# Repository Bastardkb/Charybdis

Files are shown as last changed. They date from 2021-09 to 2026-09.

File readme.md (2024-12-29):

# Charybdis

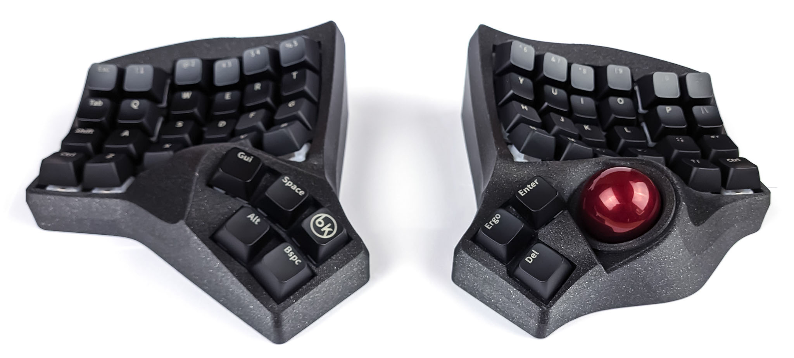
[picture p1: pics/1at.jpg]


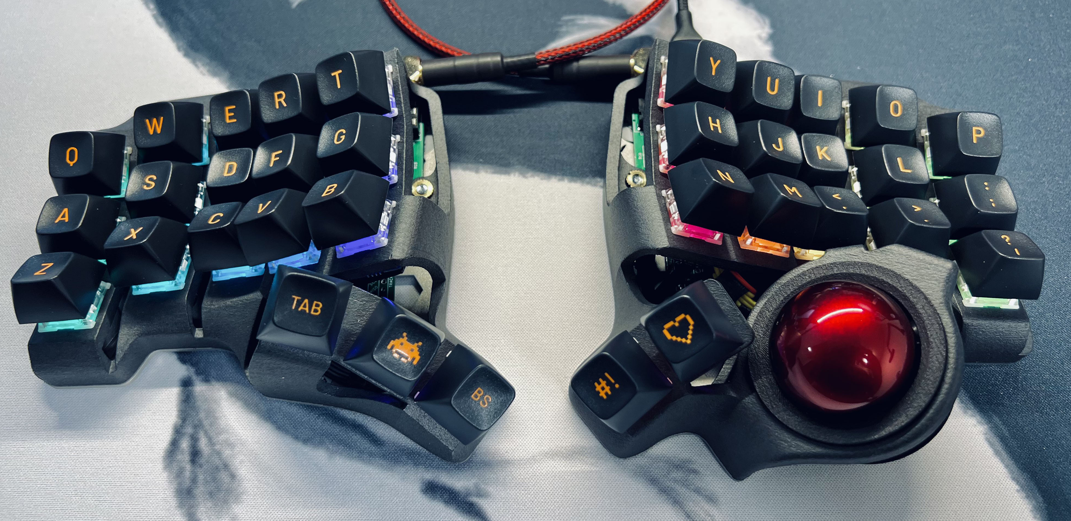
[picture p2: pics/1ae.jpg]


An ergonomic keyboard with integrated trackball.

Engineered to be a full mouse replacement solution with high-quality, custom-developed components.

There are 4x6, 3x6 "Mini" and 3x5 "Nano" versions.

Made to be used with the [Scylla](https://github.com/Bastardkb/Scylla), [TKB Mini](https://github.com/Bastardkb/TBK-Mini) or [Skeletyl](https://github.com/Bastardkb/Skeletyl) on the other half.

# Required components

## 3d prints - cases

The STL files are included in this Github repository, in the `files` folder.

You can find detailed instructions on how to print the case here:

https://docs.bastardkb.com/help/dactyl_print.html

Depending on which keyboard you are building, you will need different prints. There is a list in the table below - depending on the version number, the names will slightly vary. 

This repository is always updated with the latest version of the 3d models, and they are compatible with previous versions. For example, `charybdis.stl` might reference `charybdis3_v131.stl`. 

The 3d files might have the `stl` or `3mf` extension, depending on time of release. The extension type does not matter when slicing and printing.

**3d prints - 4x6**

There are two versions available for the Charybdis 4x6: `MK1`, and `MK2`. You can find the required files in their respective folder.

In the below table are listed the required files to construct the `MK2`, as that's the one most up to date.
The files that are compatible with both `MK1` and `MK2` are in the `4x6` folder.

| Description | File | Notes |
| --- | --- | --- |
| Right case | `4x6/MK2/charybdis.stl` | |
| Left case | | Download from the [Scylla repository](https://github.com/Bastardkb/Scylla) |
| Right plate | `4x6//MK2/plate_shield2.stl` | |
| Left plate | | Download from the [Scylla repository](https://github.com/Bastardkb/Scylla) |
| Adapter - top | `4x6/adapter_top.stl` | There is a different adapter for the 4x6 and 3x5, make sure to grab the one in the 4x6 folder ! |
| Adapter - bottom | `adapter_bottom.stl` | |
| Tent - right | `4x6/tent_alien.stl` | Optional 30 degree tent* |
| Tent - left | `4x6/tent_alien.stl` | Optional 30 degree tent, mirror the file for left* |

*The 30 degree tents are compatible with both Charybdis MK1 and MK2.

**3d prints - 3x6**

| Description | File | Notes |
| --- | --- | --- |
| Right case | `3x6 mini/Cmini.stl` | |
| Left case | | Download from the [TBK Mini repository](https://github.com/bastardkb/tbk-Mini), mirror the file for left |
| Right plate | `3x6 mini/plate.stl` | |
| Left plate | | Download from the [TBK Mini repository](https://github.com/bastardkb/tbk-Mini), mirror the file for left |
| Adapter - top | `3x5 nano/adapter_top.stl` | The 3x6 Mini uses the same top adapter as the 3x5 Nano |
| Adapter - bottom | `adapter_bottom.stl` | |
| Tent - right | `3x6 mini/tent.stl` | Optional tent* |
| Tent - left | `3x6 mini/tent.stl` | Optional tent, mirror the file for left* |

*If you are printing tents for the Charybdis Mini, there are both 30 and 5 degree versions available.

**3d prints - 3x5**

| Description | File | Notes |
| --- | --- | --- |
| Right case | `3x5 nano/charybdisnano.stl` | |
| Left case | | Download from the [Skeletyl repository](https://github.com/bastardkb/skeletyl), mirror the file for left |
| Right plate | `3x5 nano/plate.stl` | |
| Left plate | | Download from the [Skeletyl repository](https://github.com/bastardkb/skeletyl), mirror the file for left |
| Adapter - top | `3x5 nano/adapter_top.stl` | There is a different adapter for the 4x6 and 3x5, make sure to grab the one in the 3x5 folder ! |
| Adapter - bottom | `adapter_bottom.stl` | |
| Tent - right | `3x5 nano/tent/alien/tent.stl` | Optional tent* |
| Tent - left | `3x5 nano/tent/alien/tent.stl` | Optional tent, mirror the file for left* |

*If you are printing tents, there are multiple ones available for the Charybdis Nano. We recommend using the latest design which is the strongest and easiest to print - the alien version. There are both 30 and 15 degree versions available.

## Get a kit from BastardKB

You can get a full Kit, including case and all PCBs and electronics required on the shop:
https://bastardkb.com/

If you want to print the case yourself, you can also get just the electronics Kit.

## Electronic components

If you are sourcing the electronic components yourself, you can find a BOM in the [BOM](electronics_bom.md) file.

## Mods

There are some mods to add BTUs or ball bearings, check the [mods folder](files/mods/).

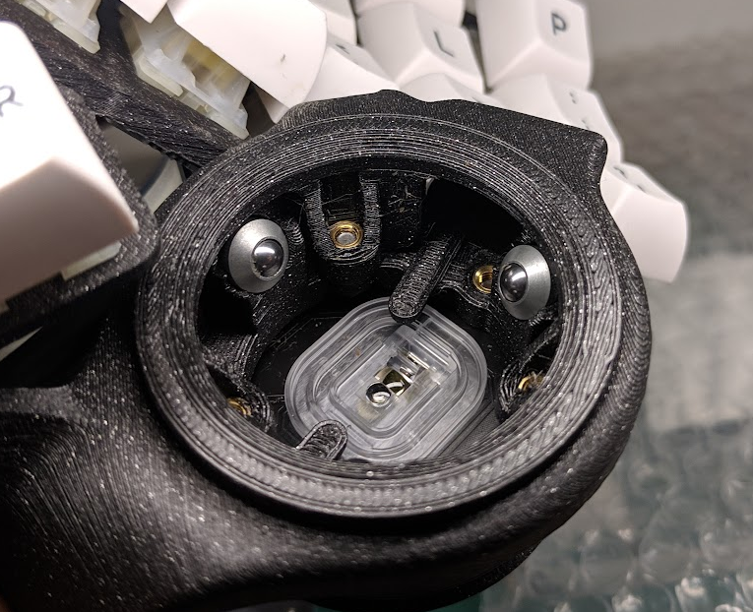
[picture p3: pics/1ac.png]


# Build guide

You can find detailed instruction on the online documentation linked below.

# Links

- Discord: https://bastardkb.com/discord
- Website: https://bastardkb.com/
- Docs: https://docs.bastardkb.com

# License 

This work is licensed under a Creative Commons Attribution-NonCommercial-ShareAlike 4.0 International License.

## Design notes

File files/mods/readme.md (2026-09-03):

# Table of contents

- [Table of contents](#table-of-contents)
- [Charybdis - generic](#charybdis---generic)
  - [BTU Mod](#btu-mod)
  - [Veichu Bearing Mod](#veichu-bearing-mod)
  - [Static Bearing Mod - Veichu drop-in replacement](#static-bearing-mod---veichu-drop-in-replacement)
  - [Static Bearing Mod](#static-bearing-mod)
  - [Static Bearing Mod - with screws](#static-bearing-mod---with-screws)
    - [Upgraded inserts for the Static Bearing Mod](#upgraded-inserts-for-the-static-bearing-mod)
  - [Trackpad mod for the Charybdis](#trackpad-mod-for-the-charybdis)
  - [Alternative sensors](#alternative-sensors)
  - [Snapfit PCB Case](#snapfit-pcb-case)
  - [AA Battery Holder](#aa-battery-holder)
  - [Trackball retainers](#trackball-retainers)
    - [PMW3360 PCB](#pmw3360-pcb)
    - [4x6 / PMW3610](#4x6--pmw3610)
- [Charybdis](#charybdis)
  - [Palm Rest](#palm-rest)
    - [Straight mod](#straight-mod)
    - [Slope mod](#slope-mod)
  - [Palm Rest for Charybdis 4x6 MKII](#palm-rest-for-charybdis-4x6-mkii)
  - [Modular adjustable tenting stand for Charybdis/Scylla](#modular-adjustable-tenting-stand-for-charybdisscylla)
    - [Base](#base)
    - [Variant with wrist wrest](#variant-with-wrist-wrest)
  - [Tripod mount plate](#tripod-mount-plate)
- [Charybdis Nano](#charybdis-nano)
  - [Midglow PCB for the Charybdis Nano tents](#midglow-pcb-for-the-charybdis-nano-tents)
  - [12mm Bosch BTU](#12mm-bosch-btu)
  - [Trackpad mod for the Charybdis Nano organic tents](#trackpad-mod-for-the-charybdis-nano-organic-tents)
  - [Chair Mount Plate](#chair-mount-plate)
  - [Modular Thumb Cluster](#modular-thumb-cluster)
  - [Sensor cover](#sensor-cover)

# Charybdis - generic

## BTU Mod

Very smooth, *very expensive*.



If you want to use BTUs rather than bearings, you will need to print the bottom adapter btu model, and source some 4.8mm BTUs.

The adapter model is designed around those: https://nl.rs-online.com/web/p/ball-transfer-units/7431408/.

Print the file in the `btu` folder.

## Veichu Bearing Mod

The veichu bearings are a cheaper alternative to the BTUs.

This uses the 7.5mm Veichu VCN310 variant.

They need to be press-fitted into the 3d print, as they have no screws.

There are 2 different versions in the `veichu` folder:

- [Bottom Veichu Model](veichu/veichu.stl) : uses M3 screw inserts
- [Bottom M3 Veichu Model](veichu/veichu_M3_screw.stl) : has M3 threads directly into the plastic, no inserts needed

## Static Bearing Mod - Veichu drop-in replacement

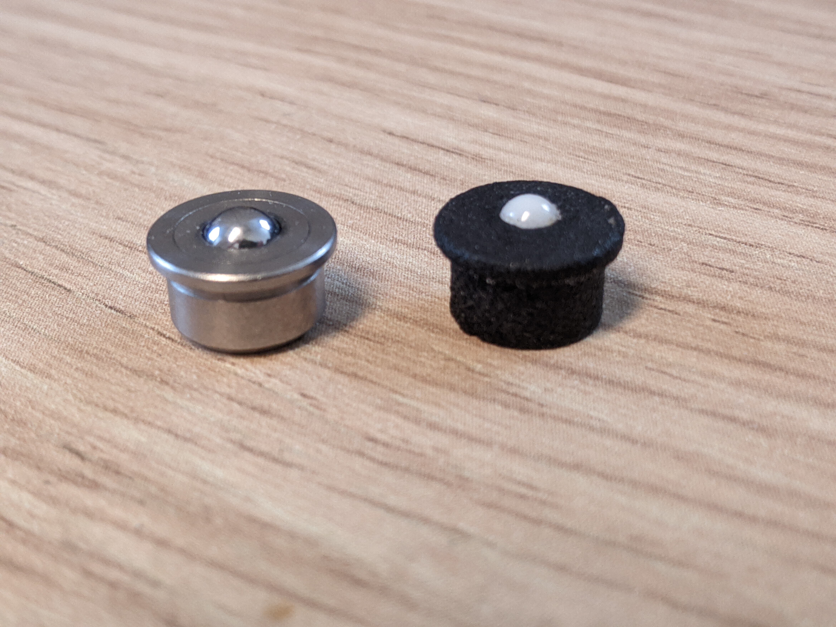
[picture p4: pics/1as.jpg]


A static bearing mod, that is a drop-in replacement for the 7.5mm Veichu VCN310 BTU.

The inserts were tested to work with MJF printing from JLCPCB. Different printing techniques have different tolerances, so you results may vary when printing with different techniques.

It was designed for 3mm ceramic balls. They press fit into the holders, can take quite a bit of force to press in. Recommend to press against a hard object like your desk.

Links:
- Use either version of the bottom models from the Veichu folder: [Bottom Veichu Model](veichu/veichu.stl) OR [Bottom M3 Veichu Model](veichu/veichu_M3_screw.stl)
- Use the [Inserts](Static-bearing-Veichu-drop-in/Static-bearing-holder_v221117.stl) from the static-bearing-veichu-drop-in folder.

## Static Bearing Mod

*This mod was made by a community member*.

Pretty smooth, *less expensive*.

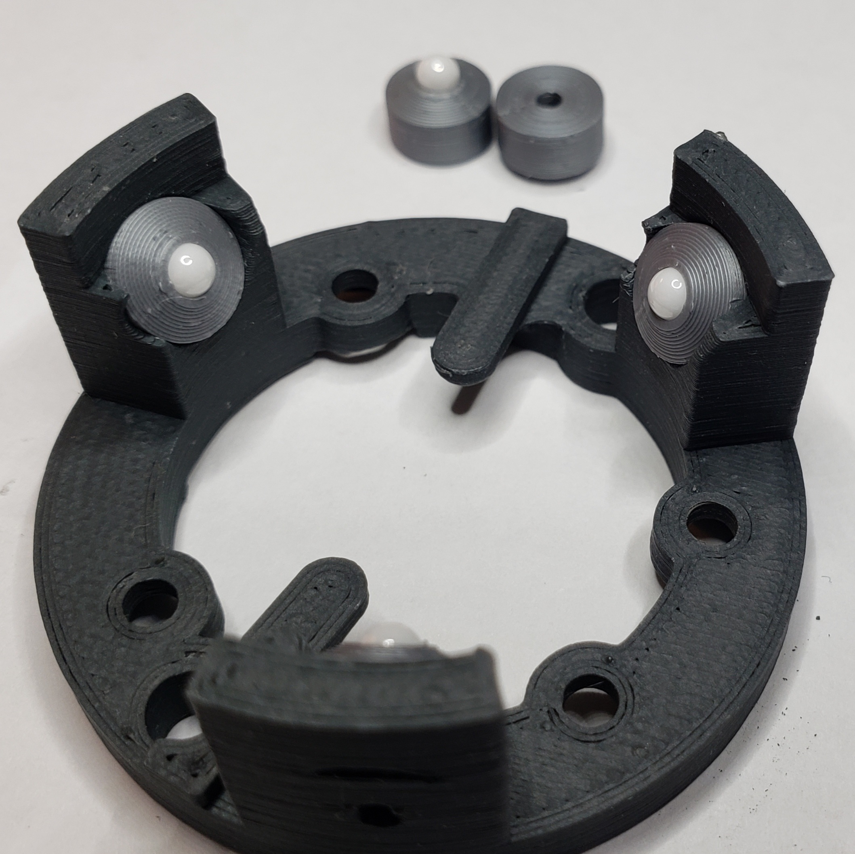
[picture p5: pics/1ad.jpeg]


You can use this option if you don't want to use bearings or buy the expensive BTU part.
There are files for 3.175mm (1/8"), and 2.5mm balls, you will need to print 3 of them as well as the bottom btu model.

Press the balls into the model then insert them into the modified [bottom btu model](btu/adapter_btu_bottom_v32.stl).

Links:
- [Bottom BTU Model](btu/adapter_btu_bottom_v32.stl)
- [Inserts](static-bearing) (choose either 3.175mm or 2.5mm)

## Static Bearing Mod - with screws

*This mod was made by a community member*.

Uses screws instead of pression fit to hold the ball inserts in the model. You will need M3 4mm screws.

Two versions : with 3.175mm balls, and 4mm balls.

Print:
- [Bottom BTU Model](static-bearing-screws/bottom.stl)
- [3.175mm insert](static-bearing-screws/balls-3.1mm/inserts.stl)
- [4mm insert](static-bearing-screws/balls-4mm/inserts.stl)

### Upgraded inserts for the Static Bearing Mod

*This mod was made by a community member*.

A bit taller of inserts, at 5mm tall, and a little more pronounced recess for the bearing ball.

The snap of the bearing ball is a little less intense as a result and gives more surface angle for the ball to rest on, resulting in a more secure seat for the ball.

Print:
- [Bottom BTU Model](static-bearing-screws/bottom.stl)
- [tall-inserts.stl](static-bearing-screws/balls-3.1mm/tall-inserts.stl)

Print and snap off supports. Sand the burrs if necessary.

## Trackpad mod for the Charybdis

Print the 2 files in the `mods/trackpad/trackball-holder` folder. Install in place of the trackball holder.
Connect the trackpad to sda, scl, vcc, gnd.

Required hardware:

| Part name | Amount | Link |
| --- | --- | --- |
| M4 8mm Torx Screw | 1 | Conrad |
| M4 screw insert, M4 X D6.0 X L5.0 | 1 | https://fr.aliexpress.com/item/4000232925592.html?spm=a2g0s.12269583.0.0.6aef4f282LZO4v |

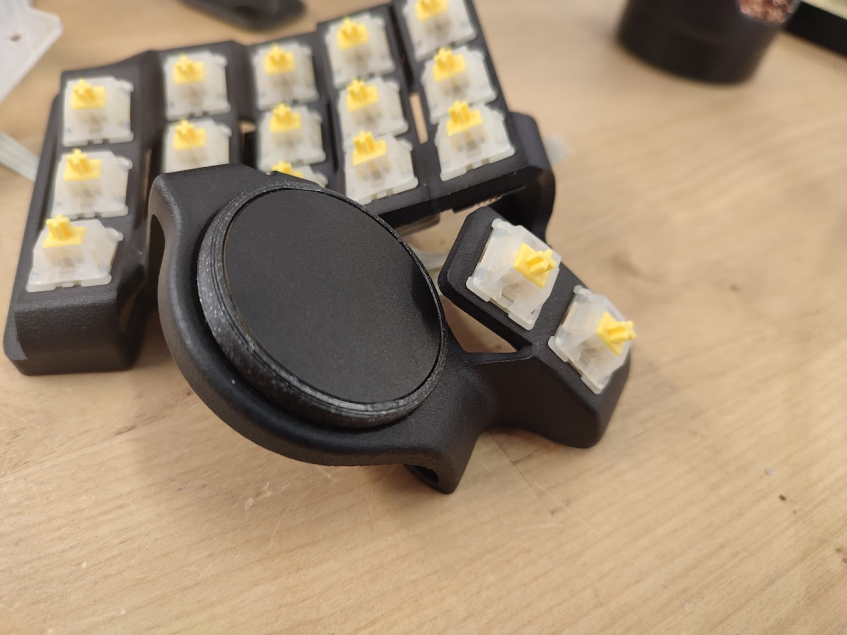
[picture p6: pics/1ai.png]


## Alternative sensors

*This mod was made by a community member*.

There are files in the [`bottom_adapter_alternative_sensors`](./bottom_adapter_alternative_sensors/README.md) directory to accomodate PMW3389 and ADNS9800 sensor PCBs.

## Snapfit PCB Case

*This mod was made by a community member*.

Made for the Charybdis Mini and Nano.

Details: [Snapfit PCB Case](./snapfit_pcb_case/).

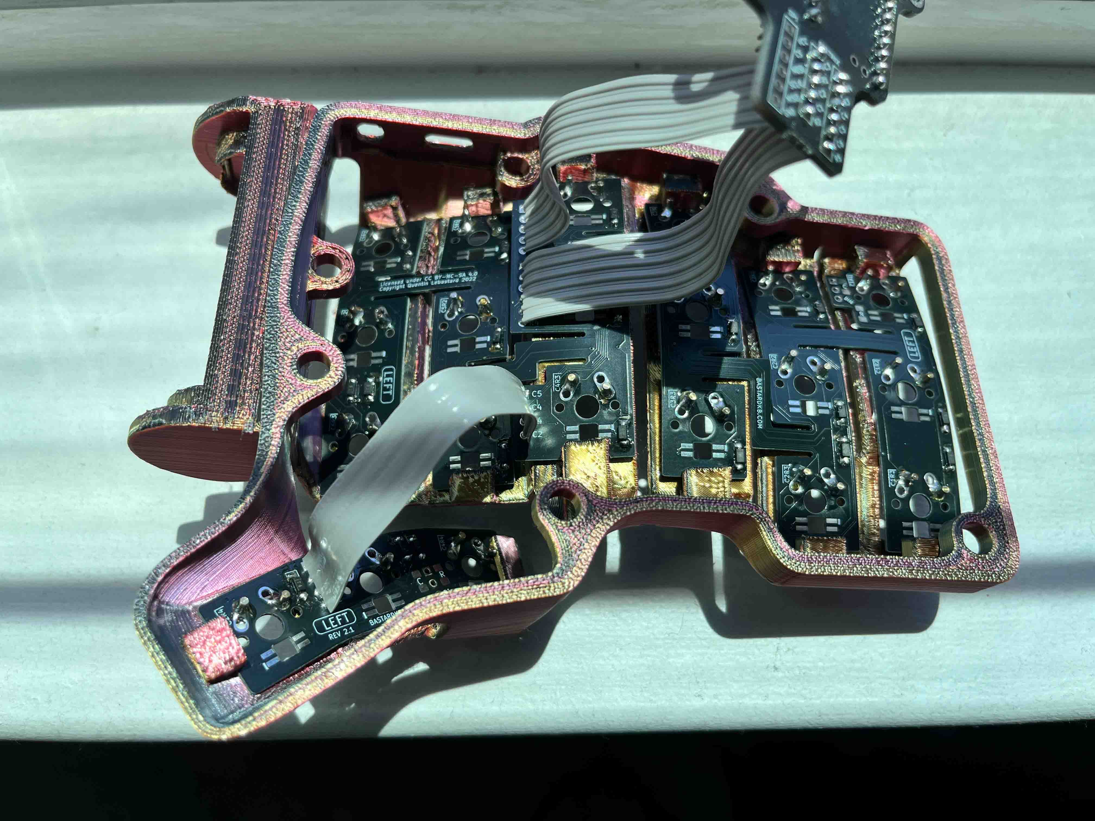
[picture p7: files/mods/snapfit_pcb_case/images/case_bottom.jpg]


## AA Battery Holder

*This mod was made by a community member*.

Made for the Charybdis Mini and Nano.

Details: [AA Battery Holder](./aa_3.7v_battery_holder/).

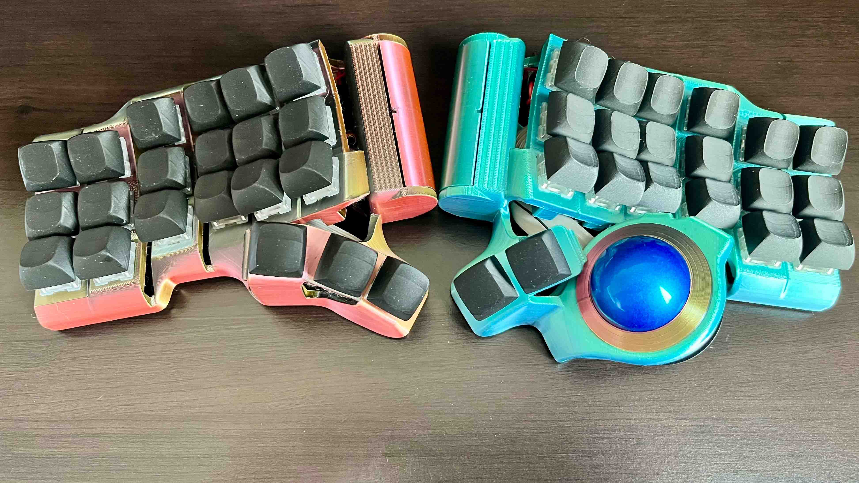
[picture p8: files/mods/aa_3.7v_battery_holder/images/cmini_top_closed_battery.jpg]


## Trackball retainers

*This mod was made by a community member*.

Use in place of the regular top adapter to prevent balls from falling.

### PMW3360 PCB

*This mod was made by a community member*.

The height of the model is adjusted for [static-beraing-screws](static-bearing-screws).

Rotating the ball may be difficult at first, but you will get used to it by putting it on and taking it off a few times and rotating it.
The screw holes of this part have an inner diameter (5mm) that allows you to glue M3 (x5x5) threaded inserts.

There are both 3x5 and 4x6 versions.

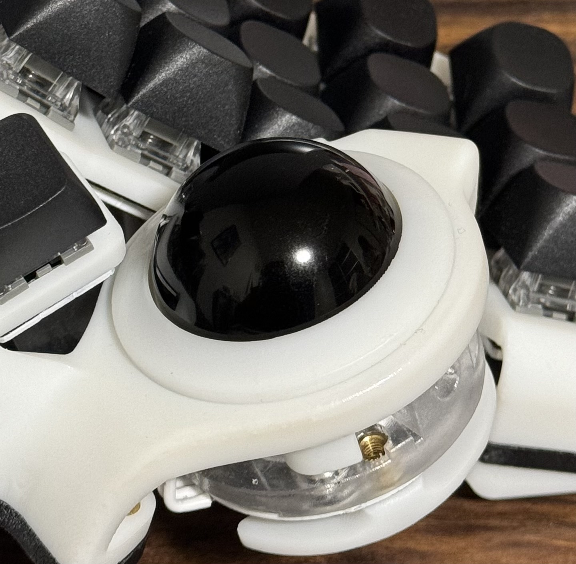
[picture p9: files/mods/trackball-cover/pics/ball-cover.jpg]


### 4x6 / PMW3610

*This mod was made by a community member*.

Specific model made for the PMW3610 PCB (for eg. bluetooth builds). Made for Zirconia 0.3mm ceramic balls.



Credit: Vzhao-L on Github.

# Charybdis

## Palm Rest

*This mod was made by a community member*.

Those palm rests are to be placed at the bottom of the keyboard, to support your palms. There are both sloped and straight versions.

For each version, there are 3 files:

- `STL`: for 3D printing
- `DWG`: for laser cutting
- `SLDPRT`: solidworks source file

The files for the Charybdis and Scylla are different:
- For the Charybdis, use the files in [4x6-palm-rest](4x6-palm-rest)
- For the Scylla, use the files from the [palm rest folder](https://github.com/Bastardkb/Scylla/tree/main/files/palm-rest)

### Straight mod
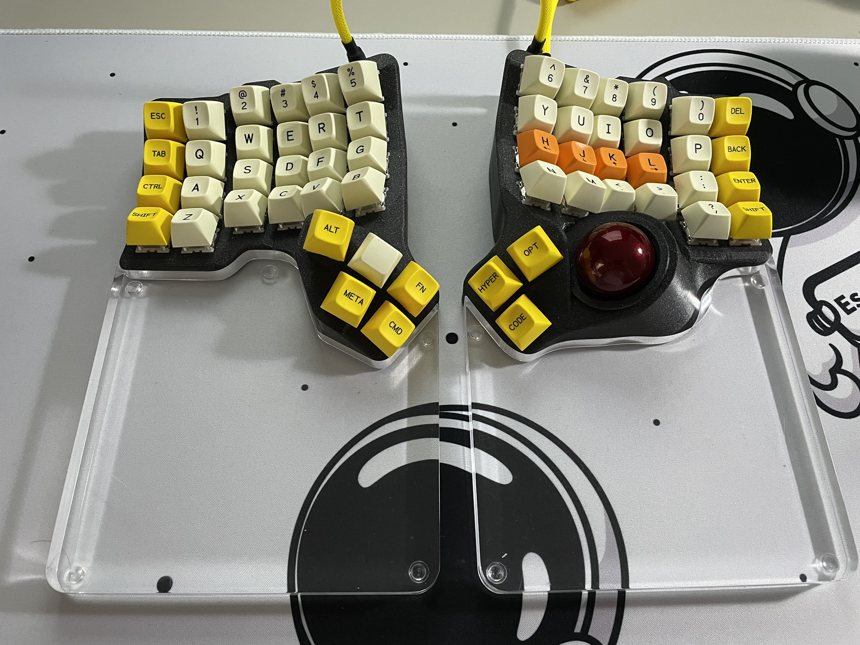
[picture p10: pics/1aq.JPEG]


### Slope mod
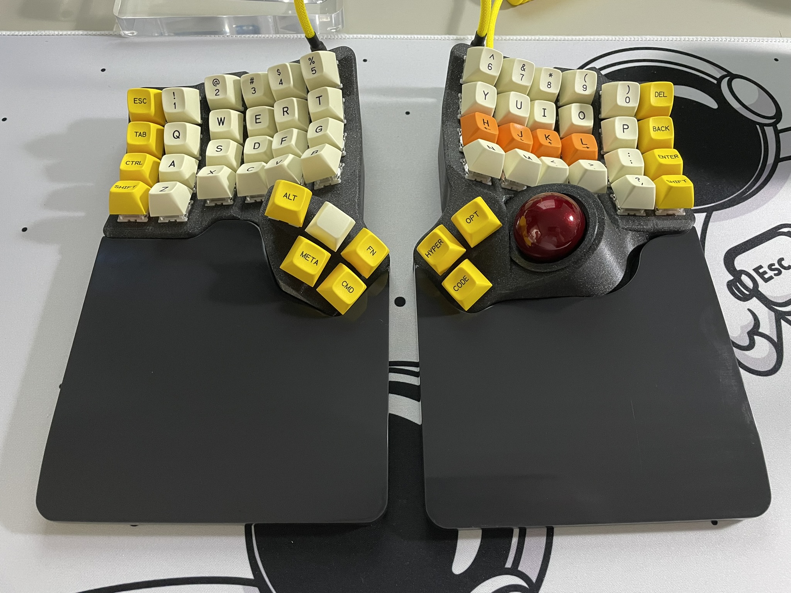
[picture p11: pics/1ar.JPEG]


## Palm Rest for Charybdis 4x6 MKII

*This mod was made by a community member*.

Wrist rests designed for larger cloth rubber mats like this one here: <https://aliexpress.com/item/1005004557222656.html>

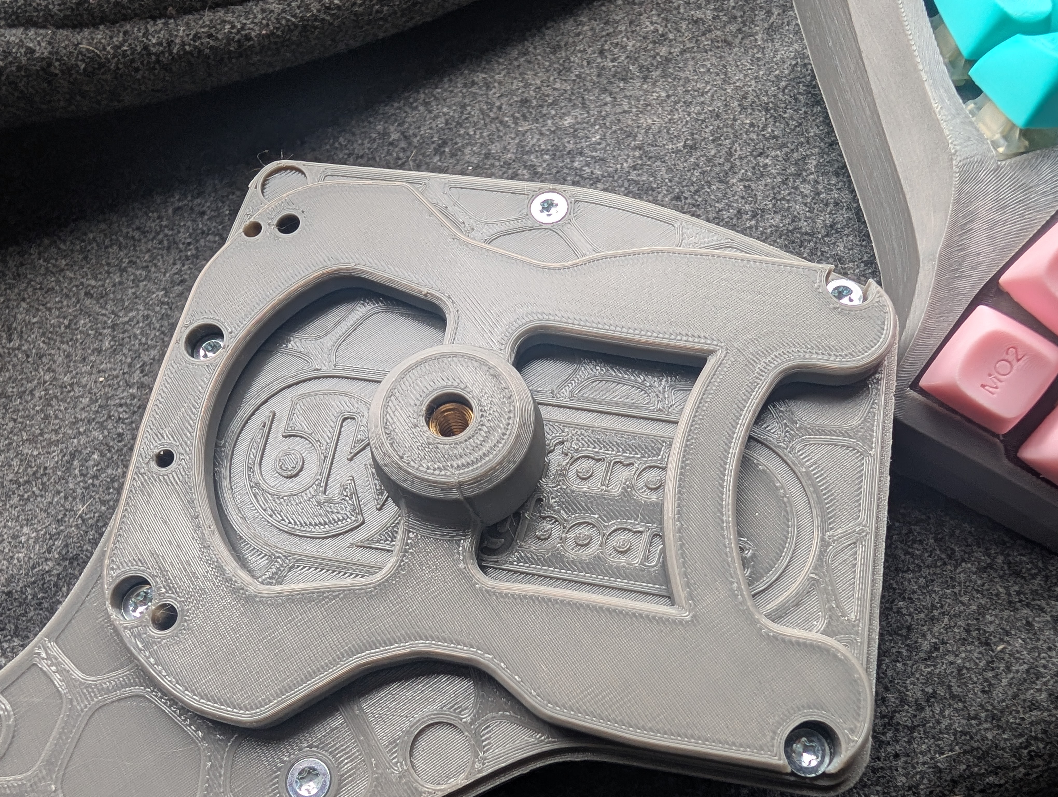
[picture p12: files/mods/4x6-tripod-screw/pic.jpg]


## Modular adjustable tenting stand for Charybdis/Scylla

*This mod was made by a community member*.

Details: [tenting-stand-with-wrist-pads/readme.md](tenting-stand-with-wrist-pads/readme.md)

### Base

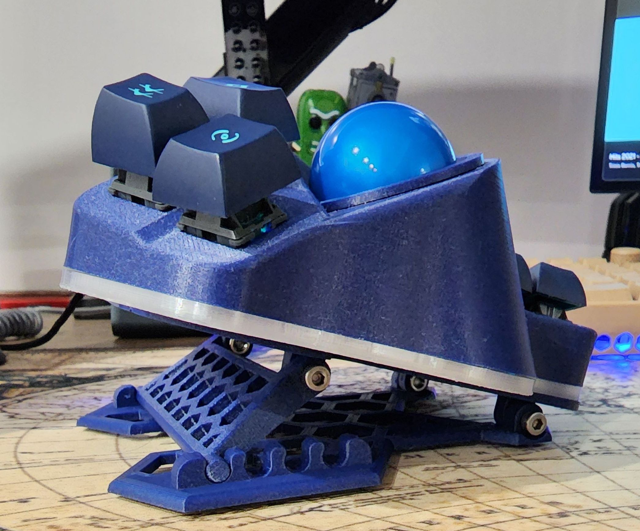
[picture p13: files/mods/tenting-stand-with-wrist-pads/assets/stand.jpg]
tenting stand


### Variant with wrist wrest

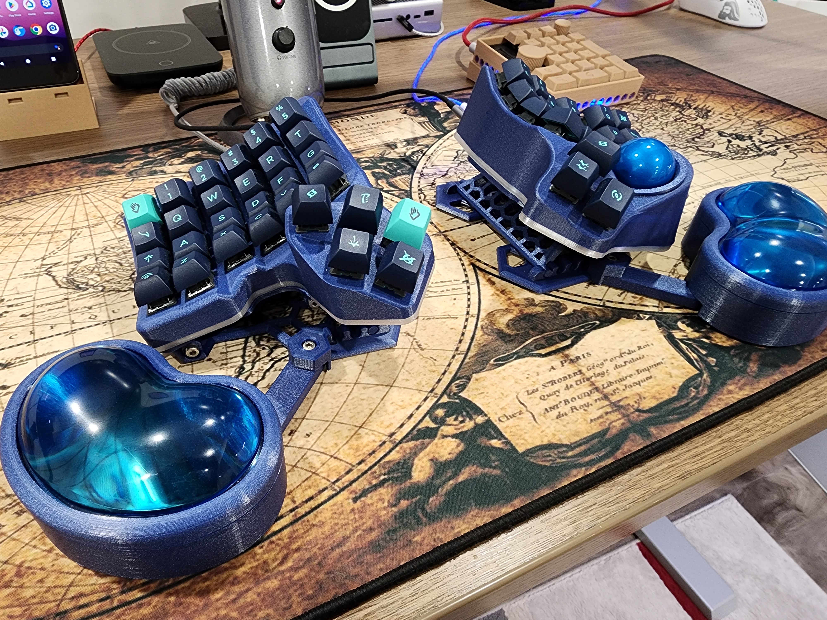
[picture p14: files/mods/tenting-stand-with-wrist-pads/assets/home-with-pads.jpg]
tending stand with wrist wrests


## Tripod mount plate

*This mod was made by a community member*.



This hefty plate mounts directly under the Charybdis plate and has an insert for a heated screw insert.
You can then screw it directly onto a tripod or magic arms. Screws into a standard 1/4 inch screw.

File is in `mods/4x6-tripod-screw`.

# Charybdis Nano

## Midglow PCB for the Charybdis Nano tents

Check repo here: https://github.com/Bastardkb/Charybdis-nano-tent-glow

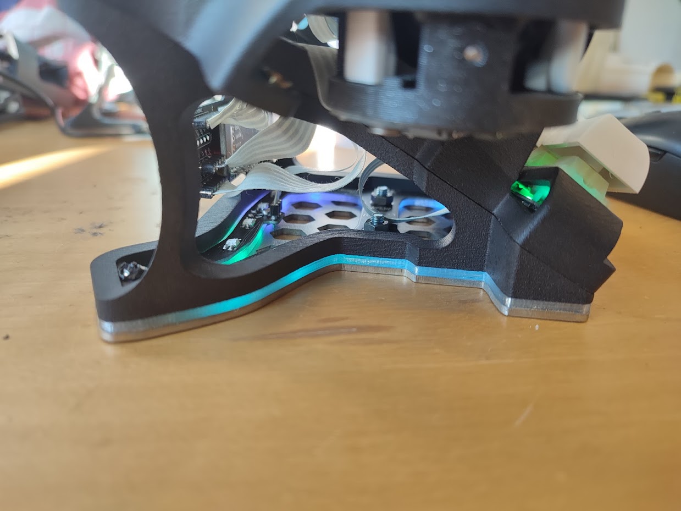
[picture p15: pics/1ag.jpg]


**Please note only the organic tent is compatible with the midglow rgb !**

## 12mm Bosch BTU

*This mod was made by a community member*.

This is an adapter for the BALL TRANSFER UNIT KU-B8-OFK R053010810 from Bosch Rexroth.

The barrel of this model is 12.6mm in diameter, with a 17mm flange which presented some challenges in creating enough space and keeping the trackball the proper distance from the sensor.

See files in `mods/12_6mm-btu-bottom-bracket`.



## Trackpad mod for the Charybdis Nano organic tents

Print the 2 files in the `mods/trackpad/3x5-tent` folder. Install on the organic tent, connect to sda, scl, vcc, gnd.

Required hardware:

| Part name | Amount | Link |
| --- | --- | --- |
| M4 8mm Torx Screw | 5 | Conrad |
| M4 screw insert, M4 X D6.0 X L5.0 | 5 | https://fr.aliexpress.com/item/4000232925592.html?spm=a2g0s.12269583.0.0.6aef4f282LZO4v |

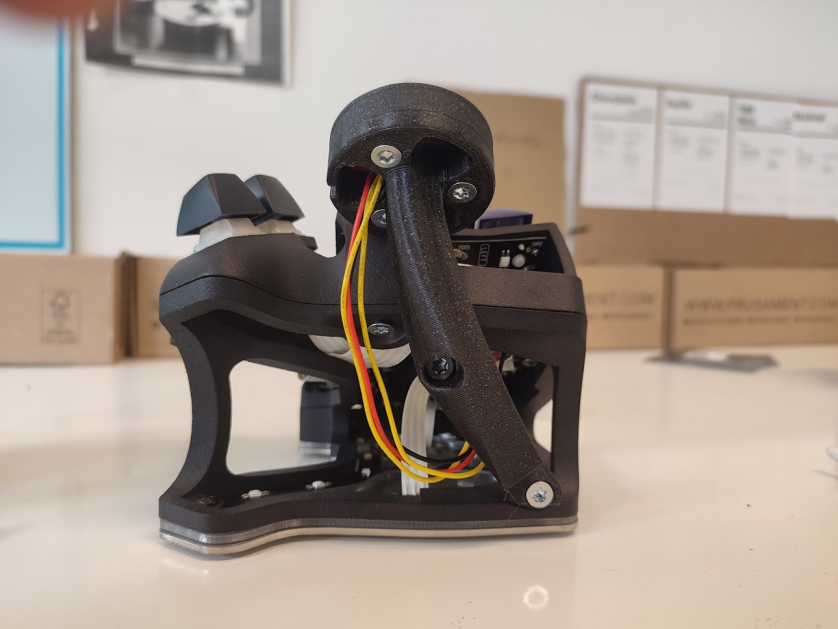
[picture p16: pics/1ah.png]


## Chair Mount Plate

*This mod was made by a community member*.

Alternate bottom plate for mounting to a chair or desk using standard camera mounting equipment. Fits 1/4 inch mounting bolt (1/4-20 UNC).
Found in the `3x5 nano/chairMountPlate` folder.

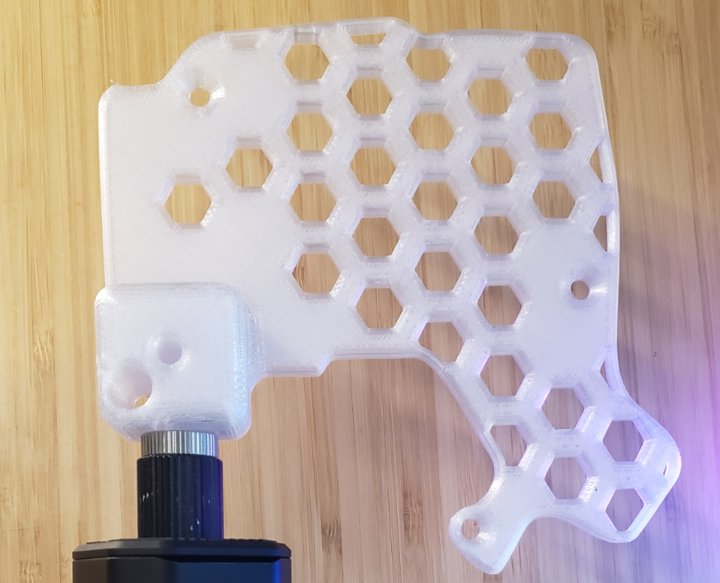
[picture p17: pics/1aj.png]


## Modular Thumb Cluster

*This mod was made by a community member*.

Based on the 3x5 Skeletyl/Charybdis Nano. This has a slightly modified plate, a 3 switch thumb cluster (ala Skeletyl), a 2 switch thumb cluster with the mount for a trackball/trackpad (ala Charybdis Nano) and a modified main body

Note: Below picture uses a standard Skeletyl main body that was cut to make room for the modular thumb cluster but a purpose printed main body should give better results!

| Part name | Amount | Link |
| --- | --- | --- |
| M4 8mm Torx Screw | 2 | Conrad |
| M4 screw insert, M4 X D6.0 X L5.0 | 2 | https://fr.aliexpress.com/item/4000232925592.html?spm=a2g0s.12269583.0.0.6aef4f282LZO4v |

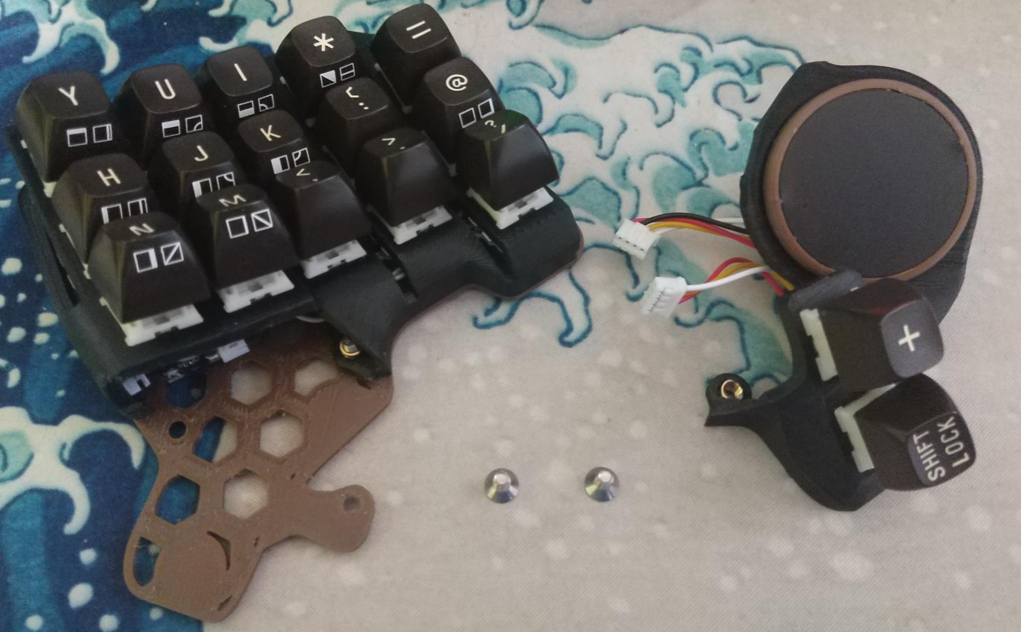
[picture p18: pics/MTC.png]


## Sensor cover

*This mod was made by a community member*.

A trackball sensor cover to be used in combination with the original bottom cover. Protects the sensor from outside elements.

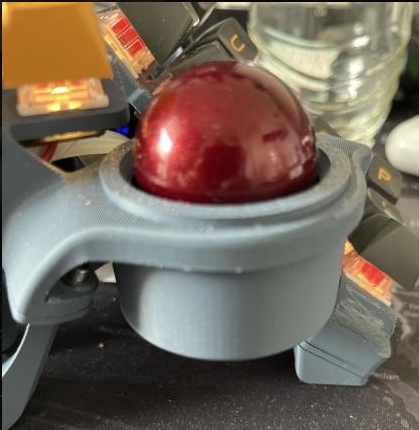
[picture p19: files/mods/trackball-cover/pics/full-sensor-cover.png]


File is in [trackball-cover](trackball-cover).

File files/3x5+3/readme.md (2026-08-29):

# 3x5+3
Modification of the Skeletyl to add a trackball, encoder and other mods. 
## Firmware
There is currently no official firmware for this build yet. Depending on which MCU is used the develop branch of QMK might need to be used.  

### Trackball
Base the firmware build off of bastardkb/charybdis/3x5 and copy the keymap from the Skeletyl to get the third thumb key on the right hand side.   
Trackball rotation adjustments would need to be made to the trackball orientation in the config.c file.  
### Encoder
To add the encoder The encoder functionality needs to be added as well as adding another key to the keymap for the push key on the encoder. The 12 LEDS need to be added to the map.   
Reference https://github.com/Bastardkb/Charybdis-EC11 for instructions on how it's wired.  
## Mounted Mods
This is a mod of the Skeletyl v4. This gives the ability to mount different mods to the inside or top of the keyboard.  
The mounting holes use M4 screws with heat inserts that are 45mm apart.  
JST XH 2.5mm connectors were used to attach the mods to the MCU board so they can be swapped out easily.

Assembled
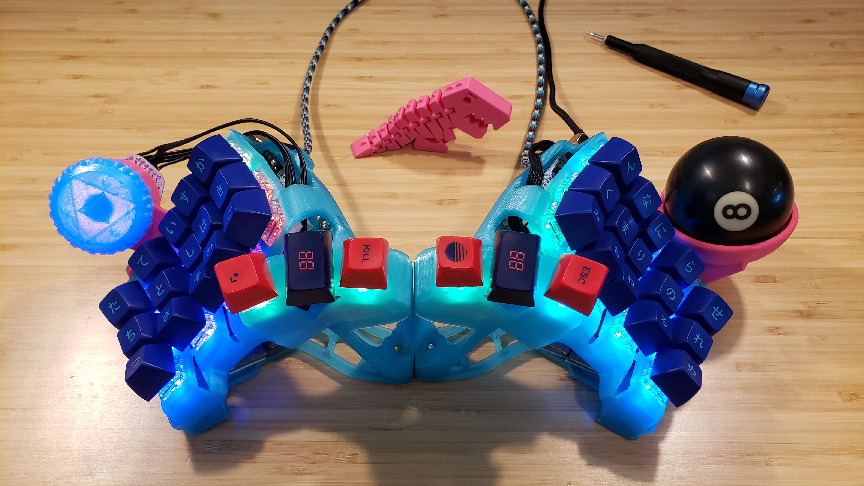
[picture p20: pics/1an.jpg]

Disassembled
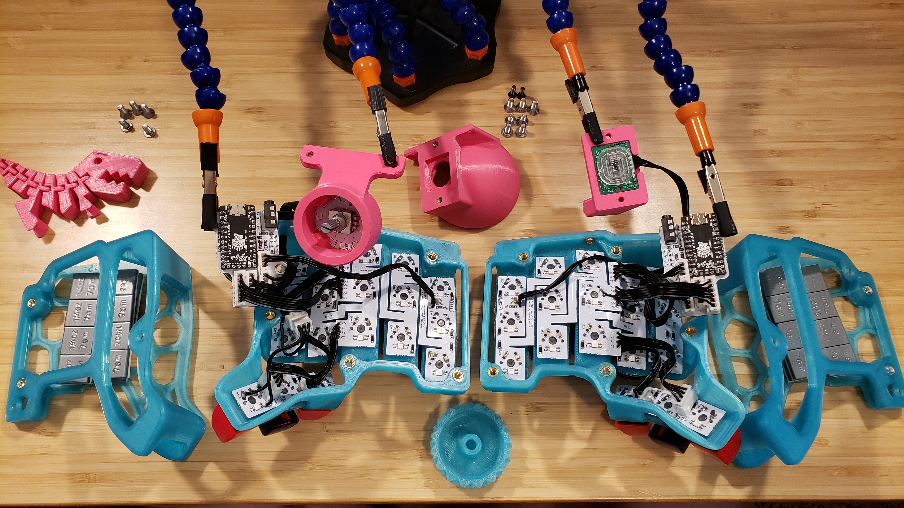
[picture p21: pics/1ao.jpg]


### Mods 
Currently only the top mount options has been developed.

#### Trackball Mod
##### Top Trackball
There are two of trackball sizes available 55mm or a 57.15 mm (2.25 inch) billiard ball.  
Two M3 screws are used to mount the cover/sensor board.
The ball bearings are 3.175mm (1/8 inch).  
They are designed for a pmw3360 or pmw3389 board from tindie.  
The charybdis-pmw-3360-sensor-pcb could be used but the bottom cover will not fit and the holes are slightly off but the heat insert could be adjusted to get it to work.  
There is a bottom version specific to the 30 degree tented version that has an angled stand to support the trackball weight.  
##### Inside Trackball
This mod uses a 34 mm trackball and the adapter from the Charybdis 3x5. This mod does work when not tented. When tented the trackball is not seated completely and does wobble.   
This could also be used to mount an encoder.  
Use the CharybdisRingMountMod file.  
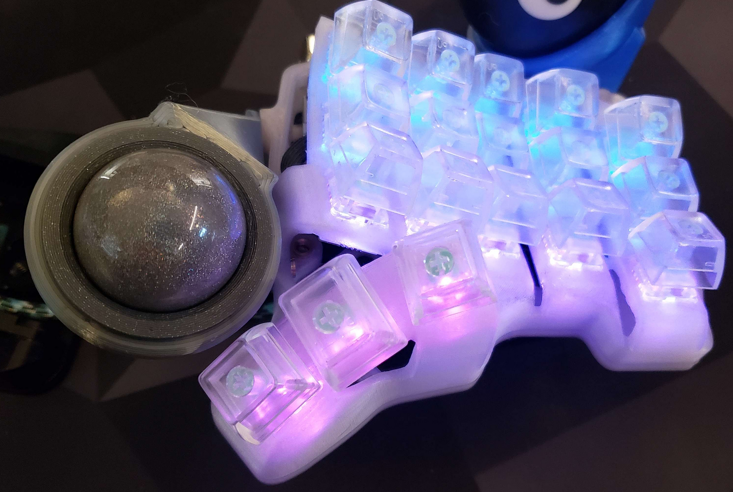
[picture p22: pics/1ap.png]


#### Encoder Mod
This uses the Charybdis EC11 pcb board with a 20mm tall EC11 encoder.  
The knobs provided use the round shaft.  
There are two knob variants a blank one and one with a second iteration Sierpiński triangle design. Both variants have domes for one finger top operation.  

### Plates
Any of the Skeletyl v4 plates can be used. The tenting models are in the Chaybdis/3x5 nano/tent the ones shown in the picture is the 30 degree alien tent with voronoi plate. Beware of interference with non tented options as the bottom of the mods protrude slightly.     
  
## HighTrackball and LowTrackball
This is a mod of the Skeletyl v3 to add the trackball mount to the inside of the keyboard.   
**A thick base plate or tenting is required for either version to sit flush on a surface.** 

*Note:* See [High Trackball File Variants](#high-trackball-file-variants) and [Low Trackball File Variants](#low-trackball-file-variants) for flat plates that work for the 3x5+3 High and Low Trackball builds. 

The tall version will not interfere with the base plate allowing any Skeletyl v3 base plates and tents to be used. 

The low version's trackball will interfere with the base plate requiring a cutout in the plate for it to fit. 

### Plates
The chair mount plates requires a heat insert for 1/4 inch camera mount threads.

High Version  
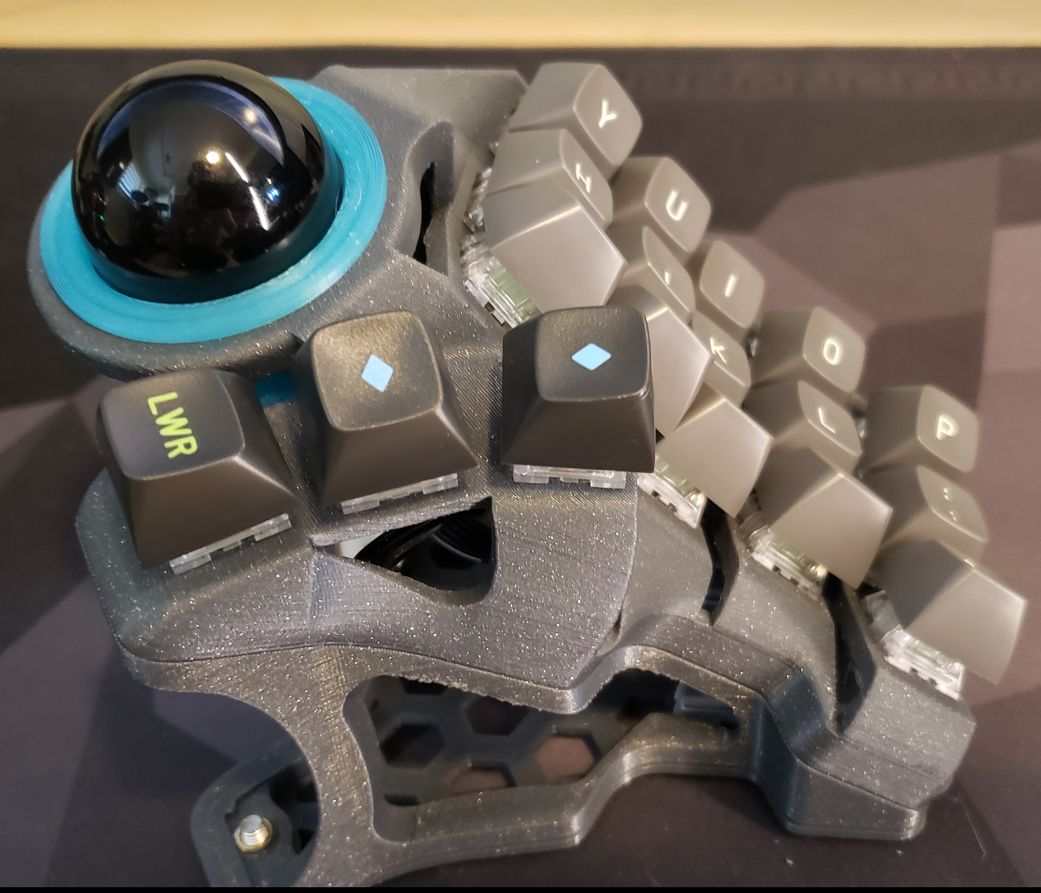
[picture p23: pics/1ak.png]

  
Low Version  
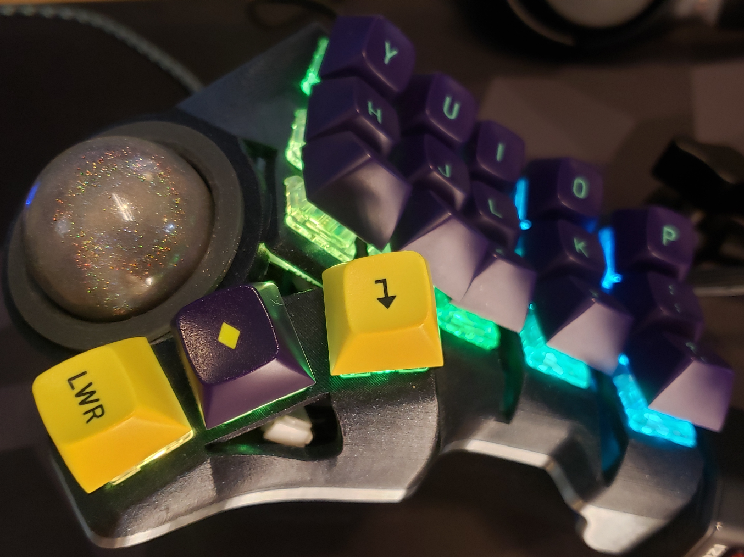
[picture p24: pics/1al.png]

  
The required cut in the plate to fit the trackball in the low version.  
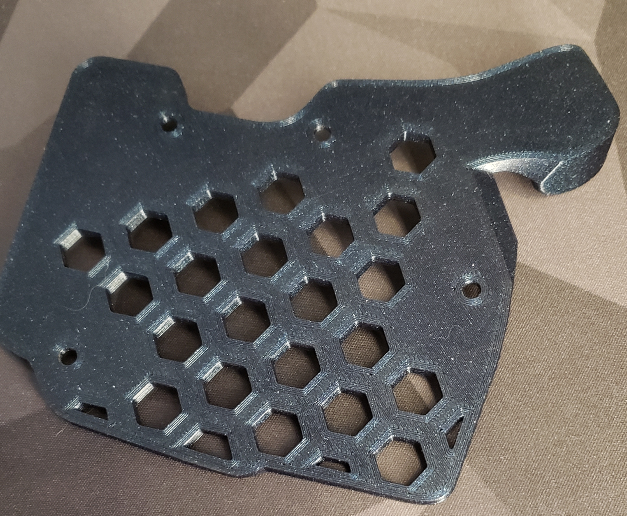
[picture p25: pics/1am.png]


### High Trackball File Variants

[flat_plate.stl](./HighTrackball/flat_plate.stl) lets you use the high trackball Charybdis flat on a desk, without a tent. It is the same as the low trackball [flat_plate.stl](./LowTrackball/flat_plate.stl), only without the cutout for the ball: the high trackball sits above the plate and never touches it. The two halves are mirrored, so print the plate once as is and once mirrored. [flat_plate.3mf](./HighTrackball/flat_plate.3mf) is the same plate in a format that is easier to open and edit.

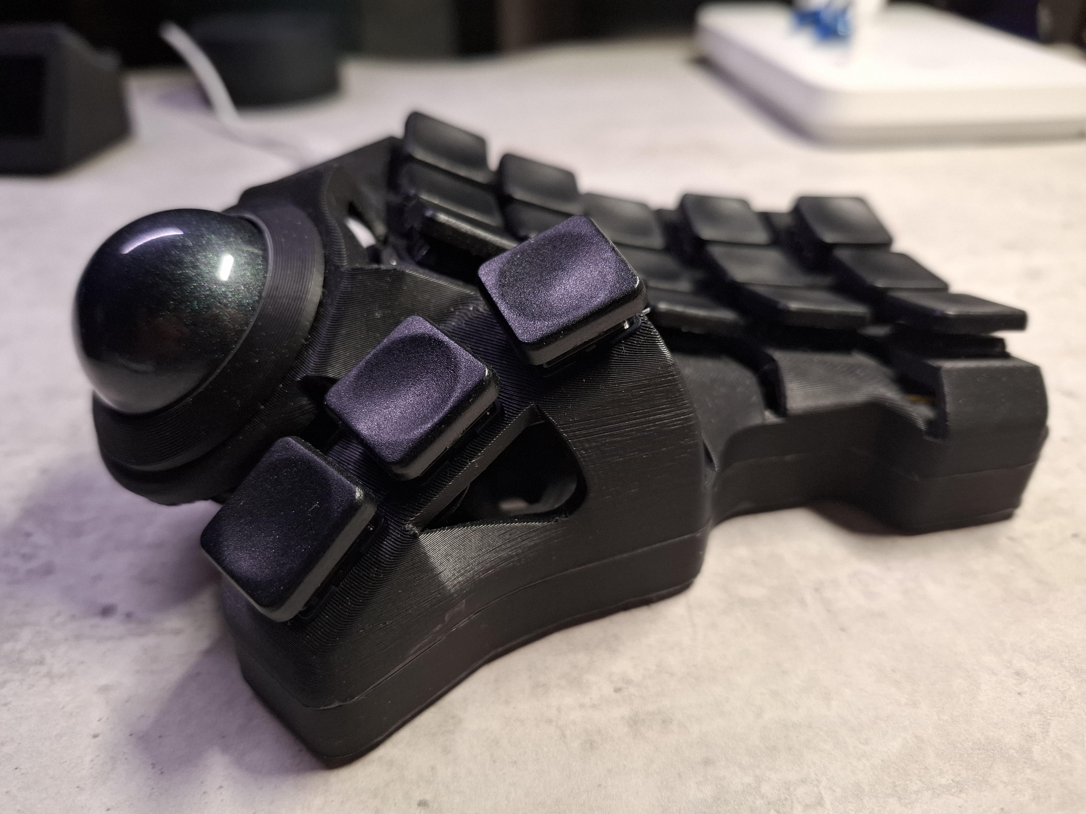
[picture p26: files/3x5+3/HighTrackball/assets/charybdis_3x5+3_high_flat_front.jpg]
charybdis_3x5+3_high_flat_front


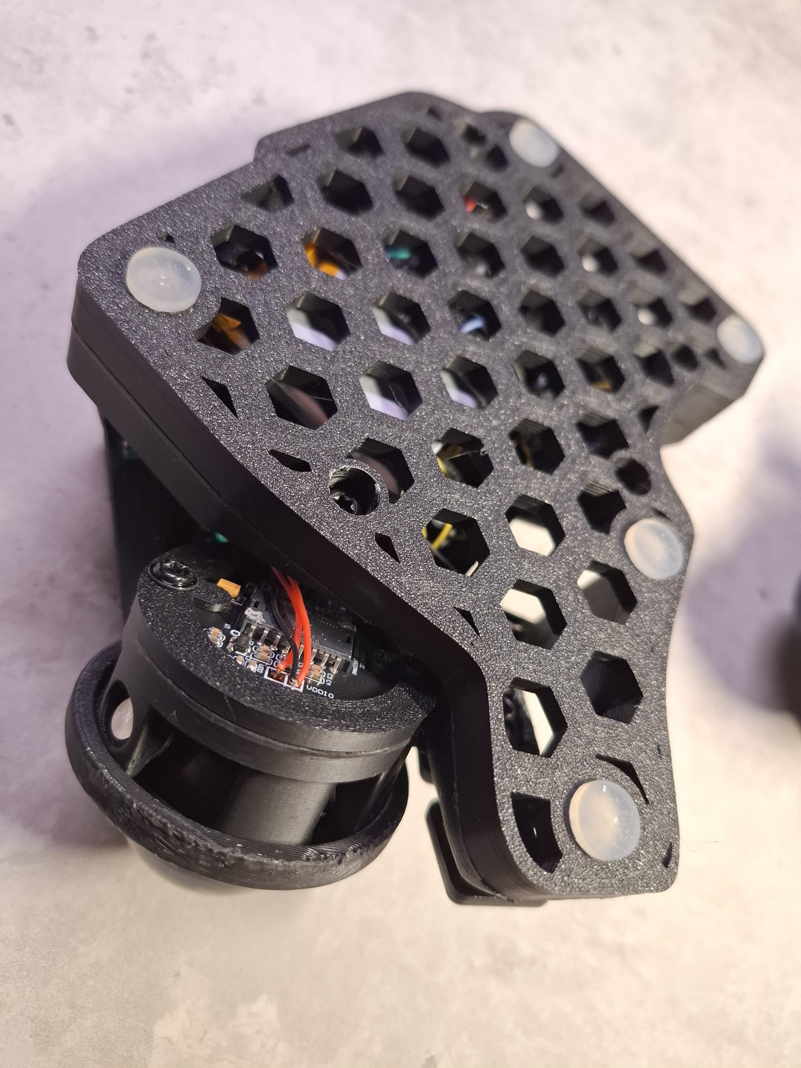
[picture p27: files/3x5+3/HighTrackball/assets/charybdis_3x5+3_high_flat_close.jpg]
charybdis_3x5+3_high_flat_close


### Low Trackball File Variants

If printing the low trackball Charybdis consider printing [3x5+3_low_clipped.stl](./LowTrackball/3x5+3_low_clipped.stl) as it removes the heat sink nut closest to the trackball mount so that it doesn't need to be clipped off aterwards. Additionally, [flat_plate.stl](./LowTrackball/flat_plate.stl) allows you to use the Charybdis without a tent.

charybdis_3x5+3_low_flat_front

charybdis_3x5+3_low_flat_close

Finally, if you are doing a handwire build then [mcu_holder.stl](./LowTrackball/mcu_holder.stl) will hold a KB2040 (or similar MCU), the TRRS jack, and a 6mm reset button.

mcu_holder_bottom

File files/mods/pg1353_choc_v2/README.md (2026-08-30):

# Kailh PG1353 (Choc V2) switches

The stock Charybdis cases are cut for MX switches. This mod is the 3x5+3 high trackball case re-cut for Kailh PG1353, sold as Choc V2.

Cutting Choc-sized windows is not enough on its own. A PG1350 (Choc V1) latches into printed plastic well enough, but the PG1353 latches are much smaller and get no grip at all, so the switches drop straight back out of the window.

The fix is two ordinary stapler staples melted into each switch window, one down each side. The latch then catches on the metal strip instead of on the plastic, and that holds: nothing has fallen out since. Taking a switch back out means bending its latches in first, otherwise they snap off.

The holes for the staples are already in the case model.

staple_in_window

A staple sitting in the switch window.

switch_retained

From below, with a switch fitted: the latches hook onto the staple.

switch_fit

How tightly the switches end up sitting in the case.

## Files

Modified from [3x5_3 high v2.stl](../../3x5%2B3/HighTrackball/3x5_3%20high%20v2.stl):

- [3x5_3_high_v2_pg1353_left.stl](./3x5_3_high_v2_pg1353_left.stl)
- [3x5_3_high_v2_pg1353_right.stl](./3x5_3_high_v2_pg1353_right.stl)

Each one also has a 3mf next to it, which is easier to open and edit.

The two halves are not mirror images of each other, so print both files as they are.

Read the section below before printing: this is one specific build, not a drop-in replacement for the stock case.

## How it differs from the stock case

**Choc-sized switch windows.** The stock case is cut for MX. Every window here is re-cut for Choc, with two extra holes per window for the staples.

**Hotswap sockets instead of a PCB.** The PG1353 body is shorter than the PG1350 and does not reach through the thickness of the case, so a PCB cannot meet the switch pins. Every switch has a Kailh hotswap socket soldered straight onto it and the matrix is hand wired. The socket sticks out to one side, and the case has small extra cut-outs for it. Those cut-outs are what stops the two halves from being mirror images.

**A trackball in both halves.** The left file is the mirrored trackball case, not a plain half. There is no version without a trackball; that one would have to be modelled.

**No jack opening.** This is a ZMK wireless build, so there is no hole for a TRRS jack.

matrix_wired

The matrix, rows and columns wired.

matrix_in_case

The wired matrix in the case, before the controller goes in.

## Staples

- No. 10 staples — the small ones for hand staplers, legs about 5 mm as they come.
- 72 of them: 36 switches, two per switch.
- Cut the legs down to 2–3 mm.

staple_length

- Push a leg into each hole and melt it in with a soldering iron, so the strip ends up flush along the side of the window.
- The staples sit in the gap between the switch body and the case wall. They come nowhere near the switch pins or the sockets.

assembled

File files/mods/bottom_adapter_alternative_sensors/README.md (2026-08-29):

# Bottom Adapter Alternative Sensors

- [Bottom Adapter Alternative Sensors](#bottom-adapter-alternative-sensors)
  - [ADNS-9800](#adns-9800)
  - [PMW-3389](#pmw-3389)
  - [PAW3360 / PMW3389 module](#paw3360--pmw3389-module)
    - [Orientation](#orientation)

## ADNS-9800

[adapter_v2_bottom_adns_9800](./adapter_v2_bottom_adns_9800.stl)

adns_9800_bottom
adns_9800_top

## PMW-3389

[adapter_v2_bottom_pmw_3389](./adapter_v2_bottom_pmw_3389.stl)

pmw_3389_bottom
pmw_3389_top

## PAW3360 / PMW3389 module

An adapter for the cheap sensor module sold on AliExpress as a "PAW3360/3389-Module", silkscreened `20240424`. Unlike the two above it is not a bottom adapter of its own — it is a thin plate that screws onto an existing ball holder in place of the original sensor PCB.

[adapter_paw3360_3389_module_20240424](./adapter_paw3360_3389_module_20240424.stl)

paw3360_3389_bottom
paw3360_3389_top

The sensor position is taken from the original Bastardkb sensor PCB, so the lens sits in the same place and at the same distance from the ball. It was printed and used on the [Veichu M3 holder](../veichu/veichu_M3_screw.stl). The other holders have not been tested, but they are all built around the original PCB, so it should fit those as well.

### Orientation

The module is symmetric and drops into the adapter either way round, but only one way is right: the row of solder pads must face the dot embossed on the adapter. The board sits off-centre in the adapter and the sensor sits off-centre on the board — the two offsets cancel out only in this orientation. Turned 180° they add up and the sensor no longer looks at the centre of the ball.

paw3360_3389_orientation

*The photo was taken with an earlier print that had a cut-out where the dot is now; the dot and the markings are drawn on.*

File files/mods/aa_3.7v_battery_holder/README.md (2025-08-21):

# Battery holder for wireless builds

The conventional wireless build for the Charybdis line of keyboards uses Li-Ion batteries, like the 401030 130mAh battery. 
The internal housing, which is specifically designed to be a wired keyboard, limits the battery size. 

Lower battery sizes offer less battery capacity, thereby reducing the battery life on the keyboard.

ZMK battery life can be computed here: https://zmk.dev/power-profiler

This mod provides (14500 3.7v Li-Ion battery) holders to the Charybdis. This will increase the battery capacity usable for Charybdis to 2500-3800mAh from current values of 130-300mAh. This repository contains files for the right and left cases for the "Mini" and "Nano" versions of the Charybdis.

## Compatibility
The following models have been confirmed working:

- Charybdis Mini with AA battery (14500 3.7v Li-Ion battery)
- Snap Fit Cases for Charybdis Mini

The following have not been tested:

- Charybdis Nano
- Tenting mechanisms

## 3D models

The files are in the `charybdis_nano` and `charybdis_mini` folder.

## Showcase

|   |
| :---------------------------------------: |
| Charybdis Mini With AA Battery (Top View) |

|                                                             |
| :-------------------------------------------------------------------------------------: |
| Charybdis Mini With AA Battery (Bottom View Showing Mill-Max Hotswap With Snap Fit PCB) |

|                                  |
| :--------------------------------------------------------------------: |
| Charybdis Mini With AA Battery (Top View Without Battery Holder Cover) |

## Build guide

A build guide can be found in the [build guide file](build_guide.md).

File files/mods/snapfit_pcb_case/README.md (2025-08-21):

# Snap Fit Cases for Charybdis Mini and Charybdis Nano

The conventional build for the Charybdis line of keyboards is to solder the switches to the PCB. This helps to hold the PCB firmly in place.

To make the Charybdis hot swappable, some force is required to keep the PCB pushed against the keyboard case. This can be achieved with:

- using copious amounts of hot glue and/or tape
- handwire each hotswap socket
- the snap fits in this repository

The snap fit files are tested for the Charybdis Mini. The rest of the keyboards have not been tested.

## 3D models

The files are in the `charybdis_nano` and `charybdis_mini` folder.

## Renders

Charybdis Mini:

|  |
| -------------------------------------- |
|                                        |

Charybdis Nano:

|  |
| ----------------------------------------------- |
|                                                 |

## Build images

This project is used to build the project "Charybdis Mini and Charybdis Nano with AA battery". Attached are images of the front and rear view of the Charybdis Mini case with snapfits and millmax-hotswappable PCBs.

Charybdis Mini bottom view:



Charybdis Mini top view:


## Installation

1. Insert the flexible PCBs by bending them and locking them in the snap fits
1. Exercise caution when bending the thumb PCB cluster as they might not be as flexible as the 3x6 or 3x5 PCB plates
1. In case you are unable to fit the PCBs in the snap fits: One potential check would be to ensure there are no supports under the snap fits

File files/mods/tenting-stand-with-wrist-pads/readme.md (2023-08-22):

# Modular adjustable tenting stand for Charybdis/Scylla

## Required hardware

| Part name | Amount | Amount with wrist supports | Link |
|---|---|---|---|
| M4 nuts | 8 | 12 | Anywhere |
| M4 bolts 14+mm length | 8  | 12 | Anywhere |
| For wrist support generic mouse gel pads from ali or amazon | 2 | 2 | [Ali](https://www.aliexpress.com/item/1005003137481242.html) or [Amzn](https://a.co/d/4aokloi) |

## Base

tenting stand

## Variant with wrist wrest

tending stand with wrist wrests

## Printing

### Base parts

- [Bottom - bottom.3mf](bottom.3mf)
- [Top plate - plate.3mf](plate.3mf) - This must be mirrored for another side
  
  Alternatively you can print remixed bottom case plates for Scylla/Charybdis, mirror appropriately if required. This should reduce several millimeters.
  
  - [Scylla bottom plate hinges](left-case-bottom-scylla.3mf)
  - [Charybdis bottom plate with hinges](right-case-bottom-charybdis.3mf)
  - [Charybdis 3x5+3 Low bottom plate with hinges](3x5+3_low_tent_plate.stl)

  Print them vertically like so: print-position
  
- [Tenting arm - tenting-arm.3mf](tenting-arm.3mf)

### Additional parts for wrist wrest

See folder `wrist-pad-variant-parts` for more files

- [Bottom plate with attachment](wrist-pad-variant-parts/bottom-with-pad-connector.3mf) - This must be mirrored for another side, also ensure pads arm attachment has supports.
- [Top part that hold gel pad - pads-holder.3mf](wrist-pad-variant-parts/pads-holder.3mf)
- [Bottom part that connects to the arm - pads-base.3mf](wrist-pad-variant-parts/pads-base.3mf)
  - [Bottom part that connects to the arm, but shorter by 5mm - pads-base-short.stl](wrist-pad-variant-parts/pads-base-short.stl)
- [Connecting arm - pads-arm.3mf](wrist-pad-variant-parts/pads-arm.3mf)
  - [Connecting arm, 50mm longer - pads-arm-extended.stl](wrist-pad-variant-parts/pads-arm-extended.stl)
- [Optional hight extension - pads-optional-extension.3mf](wrist-pad-variant-parts/pads-optional-extension.3mf)

Updated alternatives

- [Short arm for angled pad base - pads-arm-short-for-angled-base.3mf](wrist-pad-variant-parts/pads-arm-short-for-angled-base.3mf)
- [Angled bottom part that connect to the arm - pads-base-angled.3mf](wrist-pad-variant-parts/pads-base-angled.3mf)

## Source

If you wanna play around with models, I've attached fusion files:

- [Charybdis adjustable plate v3.f3d](charybdis%20adjustable%20plate%20v3.f3d) 
- [pads.f3d](wrist-pad-variant-parts/pads.f3d)

## Gallery

lowest
highest
under

top-with-pads
front-with-pads
under-with-pads

angled-pad
with-angled-pads

### Charybdis 3x5+3 Low

Charybdis 3x5+3_low_bare
Charybdis 3x5+3_low_complete
Charybdis 3x5+3_low_side

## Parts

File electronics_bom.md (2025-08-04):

| Part name | Amount (4x6) | Amount (3x6) |  Amount (3x5) | Link |
| --- | --- | --- | ---  | --- |
| Sensor PCB | 1 | 1 | 1 | https://github.com/Bastardkb/charybdis-pmw-sensor |
| Splinktegrated* | 2 | 2 | 2 | https://github.com/bastardkb/splinktegrated |
| Cables | | | | 28 AWG recommended |
| PJ320A Audio jack | 2 | 2 | 2 | |
| Button, 4x4x1.5 | 2 | 2 | 2 | https://www.aliexpress.com/item/1005001304569553.html?spm=a2g0s.9042311.0.0.27424c4dDwgcp7 |
| Bearing, MR63-3x6x2.5mm | 3 | 3 | 3 | |
| Flexible PCB for the plate (4x6)  | 2 | 0 | 0 | https://github.com/Bastardkb/Scylla-PCB-Plate |
| Flexible PCB for the plate (3x6)  | 0 | 2 | 0 | https://github.com/Bastardkb/TBK-Mini-PCB-plate |
| Flexible PCB for the plate (3x5)  | 0 | 0 | 2 | https://github.com/Bastardkb/Skeletyl-PCB-plate |
| Flexible PCB for the thumbs | 1 | 1 | 1 | https://github.com/Bastardkb/PCB_thumbs_Charybdis |
| Flexible PCB for the thumbs (4x6) | 1 | 0 | 0 | https://github.com/Bastardkb/Scylla-PCB-thumb-cluster |
| Flexible PCB for the thumbs (3x5) | 0 | 1 | 1 | https://github.com/Bastardkb/TBK-Mini-PCB-thumb-cluster |
| SOD123 Diodes | 8 | 42 | 35 | |
| BAT54C Diodes | 24 | 0 | 0 | |
| M4 8mm Torx Screw | 16 | 12 | 12 | Conrad |
| M4 screw insert, M4 X D6.0 X L5.0 | 16 | 12 | 12 | https://fr.aliexpress.com/item/4000232925592.html?spm=a2g0s.12269583.0.0.6aef4f282LZO4v |
| Screws, M3 8mm Torx | 8 | 8 | 8 | |
| Heated screw insert, M3x5x5 | 5 | 5 |  5 | |

*Alternatively, you can use the [Elite-C holder](https://github.com/Bastardkb/Elite-C-holder) with the [splinky](https://github.com/bastardkb/splinky) or any other [compatible board](https://docs.bastardkb.com/hw/rp2040-community.html). 

If you want RGB, you will also need:

| Part name |  Amount (4x6) | Amount (3x6)  | Amount (3x5)  | Link |
| --- | --- | ---| --- | --- |
| SK6812 Mini-E LEDs | 58  | 42  | 35  | Aliexpress |
| Capacitor, 1uF, size 1206 | 4  |  4 |  4 | |
| Resistor, 330Ohms, size 1206 | 4 |  4 |  4  | |
| Wires | | | | 28 AWG recommended, Black, Red, Color |
| Ribbon cables Flexstrip | 6 | 6  | 6 | |

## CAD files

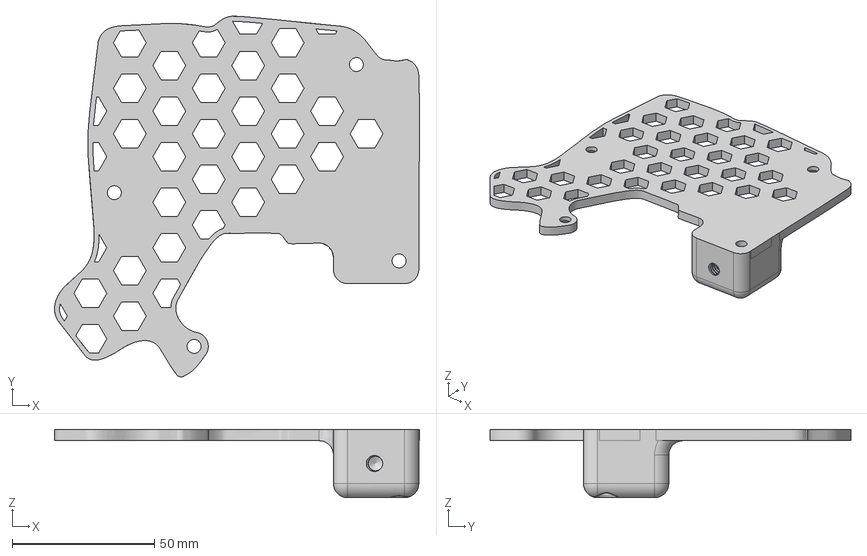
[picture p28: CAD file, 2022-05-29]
files/3x5 nano/chairMountPlate/charybdisnano_ChairMountPlate_v13.step
128.2 x 126.7 x 24.0 mm

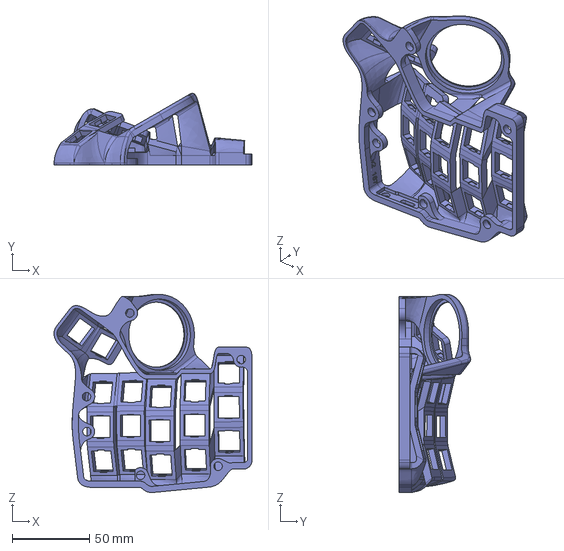
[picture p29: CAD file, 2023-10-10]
files/3x5 nano/charybdisnano_v2_v187.step
128.0 x 46.2 x 128.1 mm

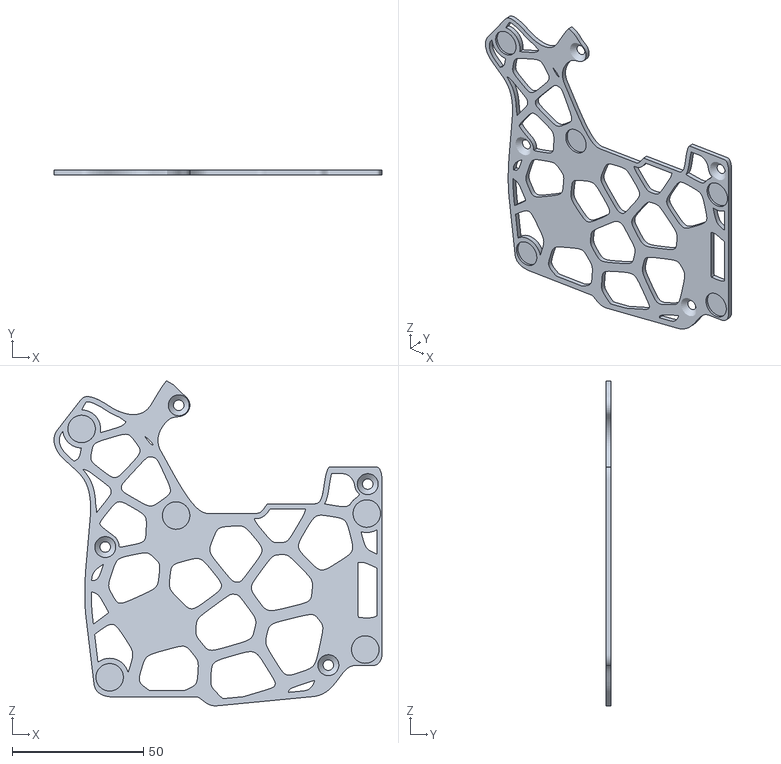
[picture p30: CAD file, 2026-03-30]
files/3x5 nano/magnetic system/cnano plate right.stl
125.0 x 2.00 x 123.7

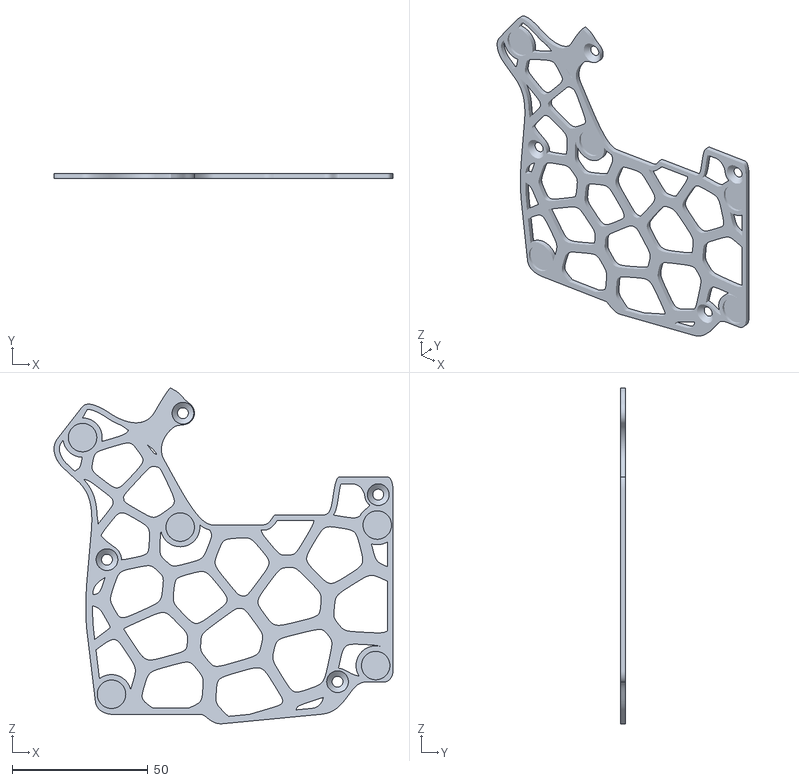
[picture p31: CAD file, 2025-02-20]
files/3x5 nano/plates/alien_flush_v1_2.stl
125.0 x 2.00 x 123.7

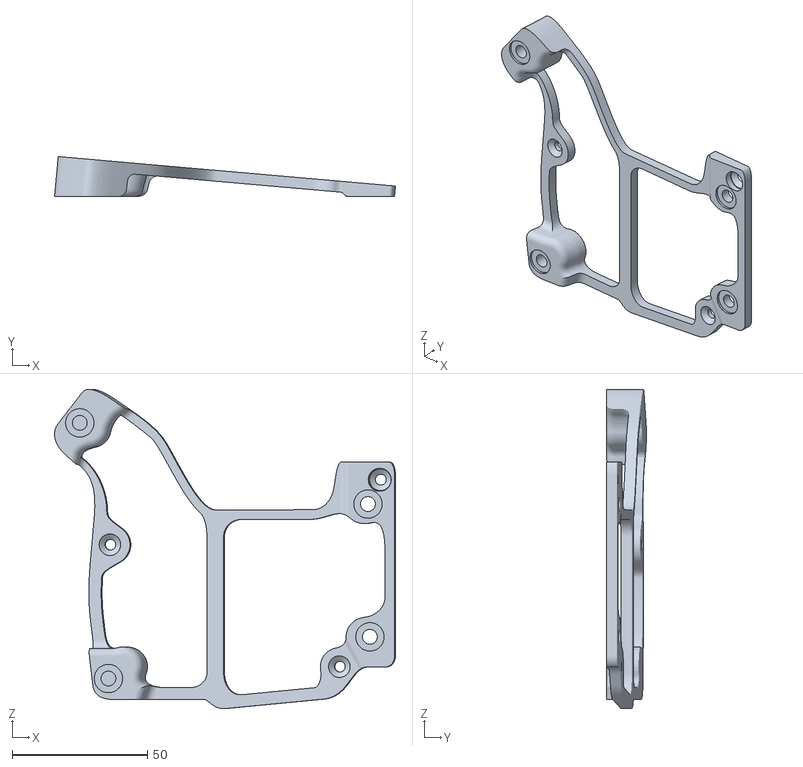
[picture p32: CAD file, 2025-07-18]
files/3x5 nano/tent/alien/tent5deg_v11.stl
125.8 x 14.7 x 117.9

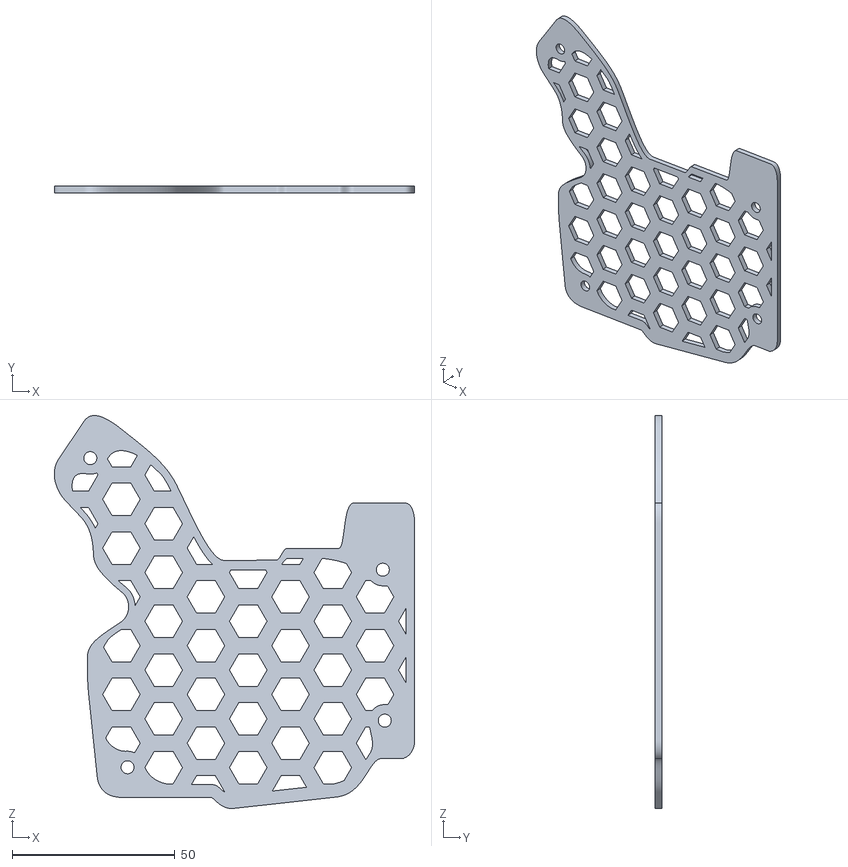
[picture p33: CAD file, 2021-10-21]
files/3x5 nano/tent/normal/tent30deg_plate_v1_9.stl
110.8 x 2.00 x 120.9

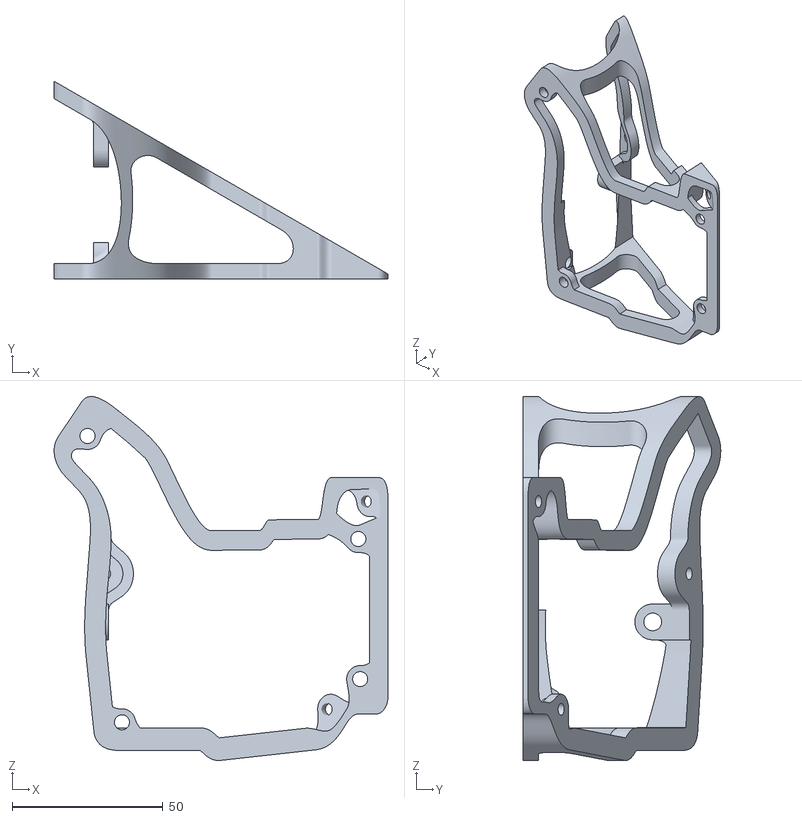
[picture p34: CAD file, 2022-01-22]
files/3x5 nano/tent/organic/tent_v1_45.stl
110.8 x 65.6 x 120.9

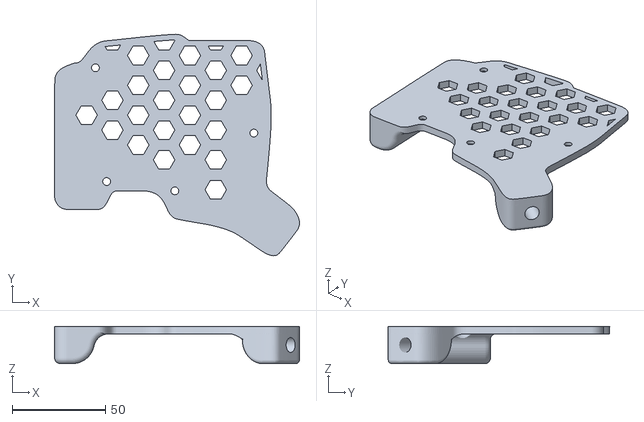
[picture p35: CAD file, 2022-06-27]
files/3x5+3/HighTrackball/chairMountPlate/3x5_3 low chairMount.stl
131.4 x 118.8 x 20.0

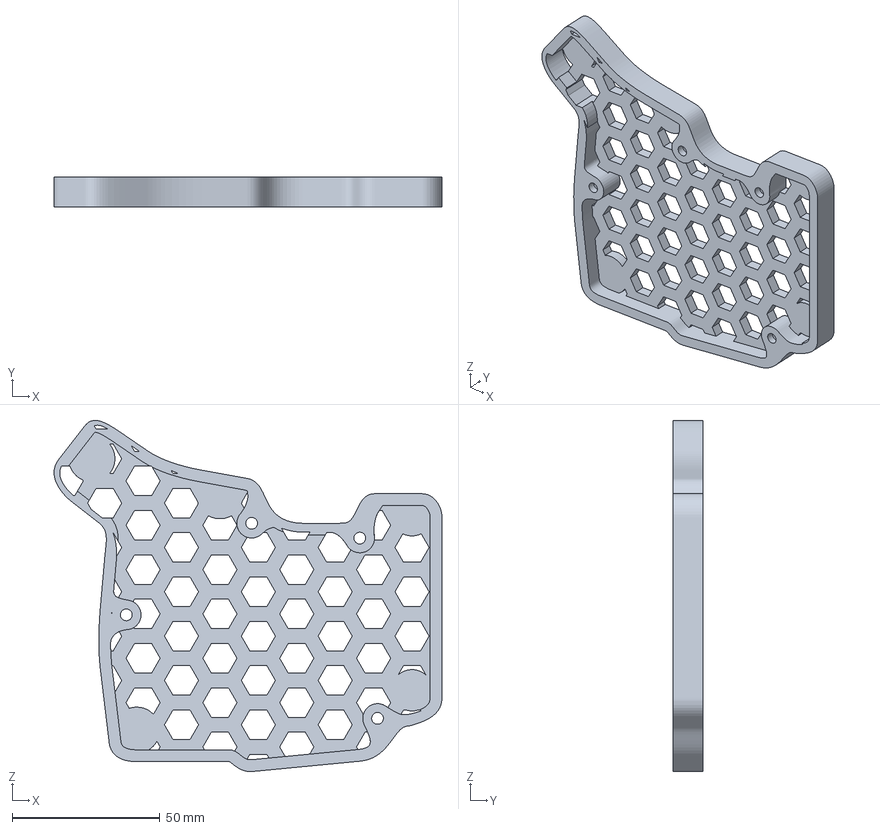
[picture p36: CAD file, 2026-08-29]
files/3x5+3/HighTrackball/flat_plate.3mf
131.3 x 10.0 x 118.8 mm

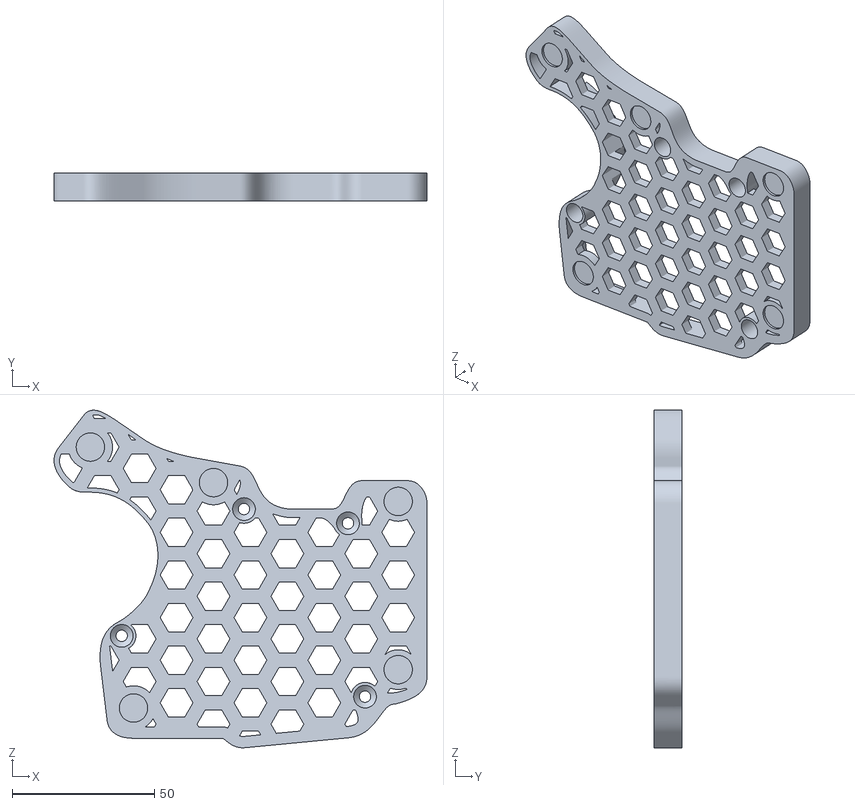
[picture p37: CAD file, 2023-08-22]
files/3x5+3/LowTrackball/flat_plate.stl
131.3 x 10.0 x 118.8

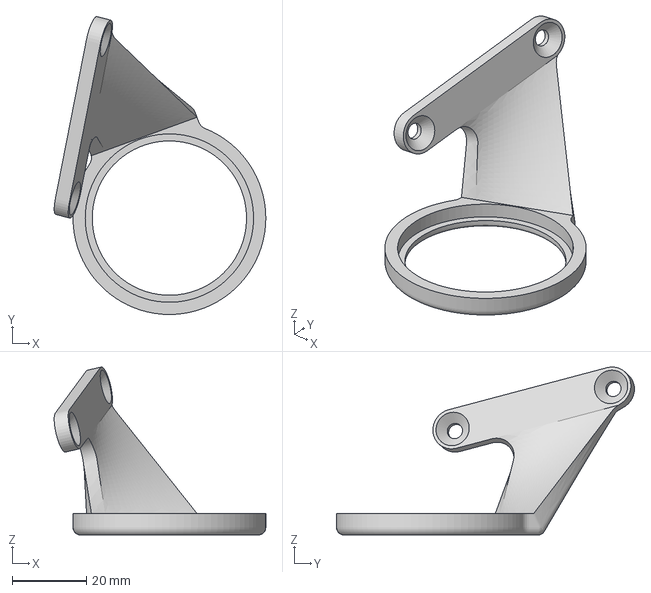
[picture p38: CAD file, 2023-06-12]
files/3x5+3/MountedMods/CharybdisRingMountMod v4.3mf
57.1 x 80.4 x 45.3 mm

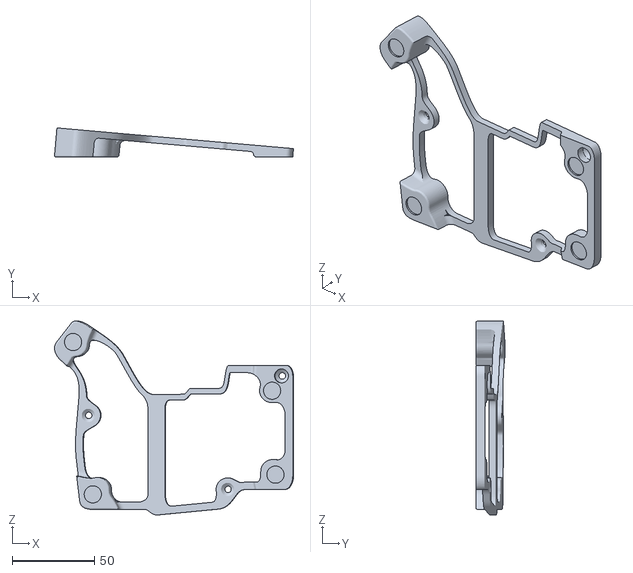
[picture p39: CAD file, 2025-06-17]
files/3x6 mini/tent_3x6_5deg_flush.stl
145.3 x 17.7 x 117.9

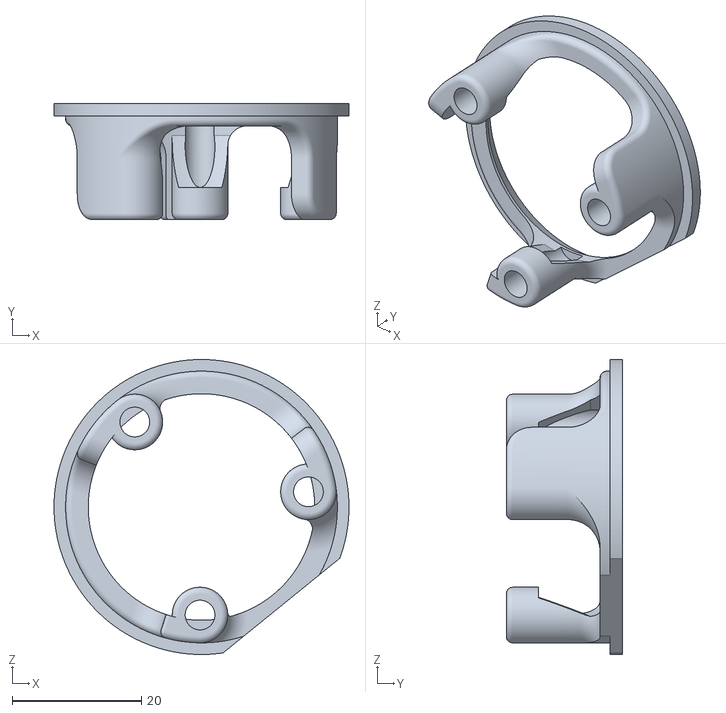
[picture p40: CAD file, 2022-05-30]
files/4x6/adapter_v4_v4_top.stl
45.6 x 18.0 x 45.6

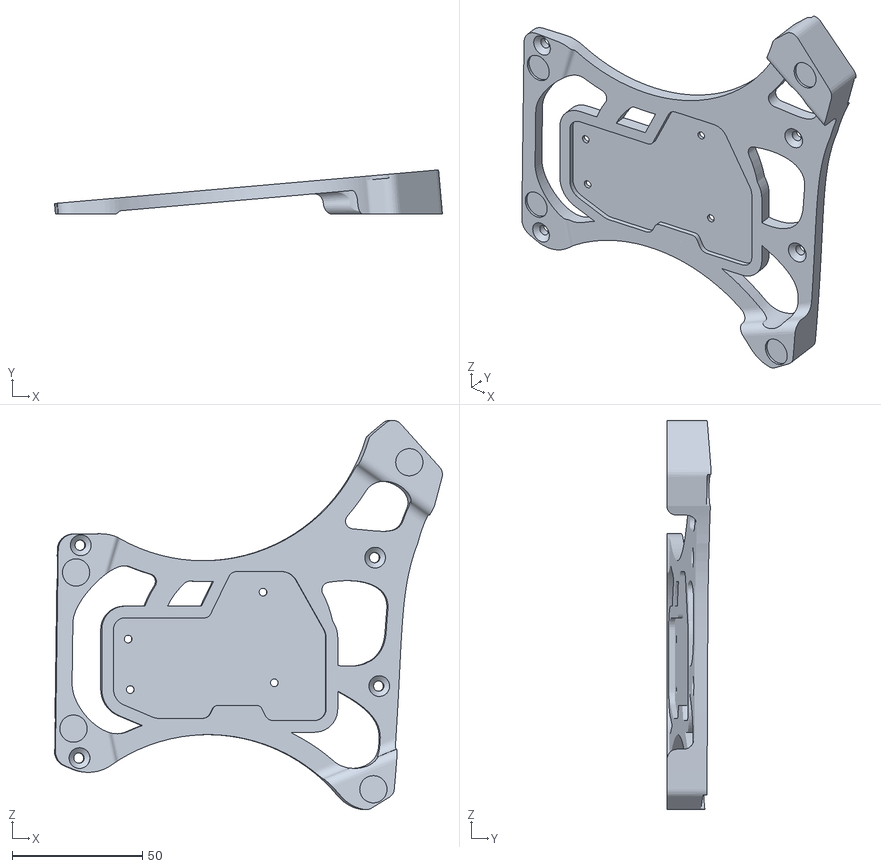
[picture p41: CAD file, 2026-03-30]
files/4x6/MK2/magtent.stl
149.1 x 17.0 x 149.6

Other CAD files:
files/3x5+3/LowTrackball/chairMountPlate/3x5_3 low chairMount.stl
files/adapter_v4_bottom_v17.stl
files/mods/4x6-palm-rest-mkII/charybdis_v4_247_right_with_pads.stl
files/mods/4x6-palm-rest/Charybdis-PlamRest-Straight.SLDPRT
files/3x5 nano/adapter_v2_top_v75.stl
files/3x5 nano/chairMountPlate/charybdisNano_plate_v13.stl
files/3x5 nano/charybdisnano_v2_v187.stl
files/3x5 nano/magnetic system/magtent.stl
files/3x5 nano/magnetic system/skeletyl plate.stl
files/3x5 nano/plates/alien_v2_185.dxf
files/3x5 nano/plates/alien_v2_185.stl
files/3x5 nano/plates/hex_v1_150.stl
files/3x5 nano/plates/magsafe_3dp_v0_1.stl
files/3x5 nano/plates/metal_magnet_v21.dxf
files/3x5 nano/plates/plate_steel_cutting_hex.dxf
files/3x5 nano/tent/alien/plate_voronoi_v1_5.dxf
files/3x5 nano/tent/alien/plate_voronoi_v1_5.stl
files/3x5 nano/tent/alien/tent15deg_v2_27.stl
files/3x5 nano/tent/alien/tent_flush_v8_1.stl
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

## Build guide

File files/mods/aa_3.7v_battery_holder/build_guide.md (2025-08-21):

# Build Guide

Follow the wireless build guide detailed in [the 280Zo charybdis wireless mini build guide](https://github.com/280Zo/charybdis-wireless-mini-3x6-build-guide). We use the same build with modifications in 2 places:

- battery
- toggle switch

# Table of contents
- [Build Guide](#build-guide)
- [Table of contents](#table-of-contents)
- [Required Materials](#required-materials)
- [Battery Connections](#battery-connections)
- [Toggle Switch](#toggle-switch)
- [Battery Holder Cover](#battery-holder-cover)
- [Notes](#notes)

# Required Materials

| Part | Quantity |
| --- | --- |
| 14500 3.7v AA Battery (14mm*50mm) | 2 |
| [AA Battery Contact Plates - max dimensions 10mm*10mm](https://www.aliexpress.com/item/2251832697974737.html?spm=a2g0o.order_list.order_list_main.104.45091802w1A1m8) | 2 pairs  |
| [Vertical Right Angle Toggle Switch  - 7mm MTS-102C3 variant](https://www.aliexpress.us/item/3256808105874261.html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) | 1 |
| Cylindrical Magnets (4mm*2mm) | 1 |

# Battery Connections

1. Solder the wires to the AA battery contact plates
1. Insert the wires soldered to the battery contact plates through the holes in the battery holder
1. Note that the negative terminal wire (the one attached to the spring plate) will go inside the hole in the battery holder that is closest to the thumb cluster. You will be able to visually notice that this side has more depth so as to house the spring
1. Once inserted through these holes, solder the battery terminal wires to the appropriate battery power pins

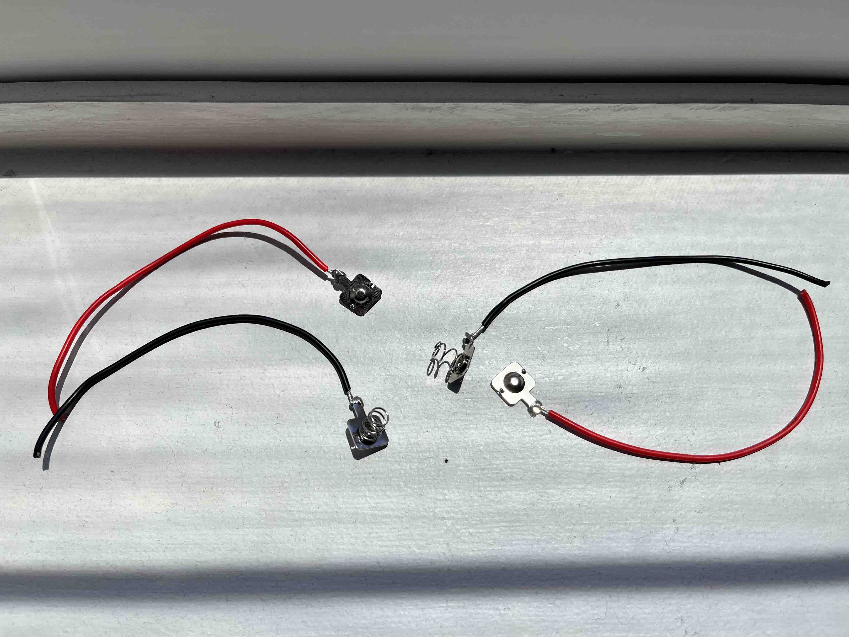
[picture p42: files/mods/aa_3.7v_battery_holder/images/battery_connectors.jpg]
|  |
| :--------------------------------: |
|           Battery Plates           |

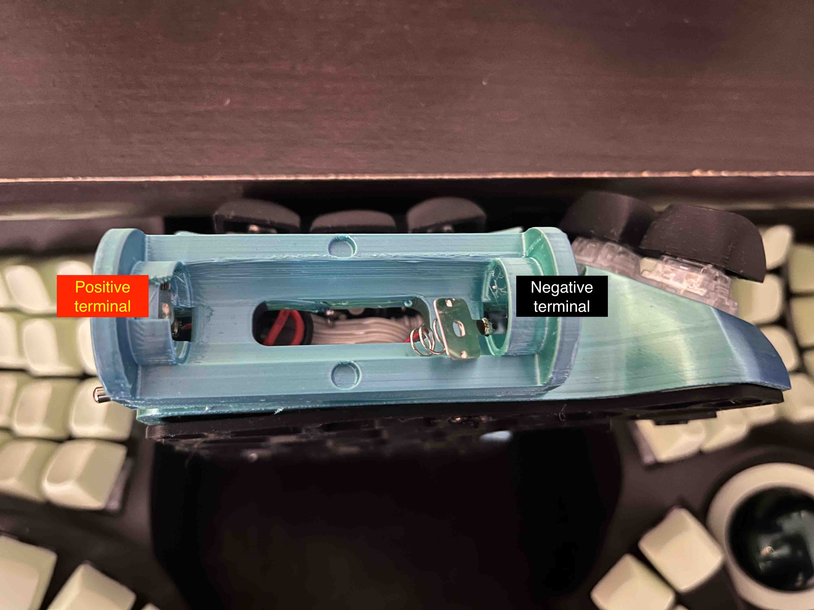
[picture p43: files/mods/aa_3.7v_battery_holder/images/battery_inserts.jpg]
|  |
| :-----------------------------: |
|         Battery Inserts         |

# Toggle Switch

We need a toggle switch for easy access to toggle the keyboard ON/OFF.

1. Re-purpose the TRRS cable hole in the case for the toggle switch. Use a deburring tool (or soldering iron) to increase the diameter of the hole if needed
2. Depending on the switches you used, you might need to orient the switch in such a way that the pins of the toggle switches face the keycaps

# Battery Holder Cover

The dimensions of the cover are such that it exactly fits the battery holder. Using some amount of force to secure it should keep it in place firmly without any locks/magnetic snap fits.

Inserts are designed to work with cylindrical magnets of dimensions 4mm*2mm both on the battery holder and the battery cover.

# Notes

1. If the build is being done with a nice!nano or similar clone, the charge ICs onboard only have overcharge protection. It is strongly recommended make sure to use AA(14500 3.7v) cells that have their own protection circuit to prevent overdischarge/undervoltage situations

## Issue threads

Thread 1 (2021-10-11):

Are BTU adapters compatible with Charybdis 4x6 version?

JGrzybowski, 2021-10-11:
As stated in the title, are BTU adapter files in 3x5 directory compatible with 4x6 files?
If so, it might be convinient to put them in the separete direcotry for BTU mod.

LinuxBozo, 2022-01-15:
FWIW, I'm actively using the printable BTU mod on a 4x6 with great success. Works so much smoother than the roller bearings. Si3N4 ceramic bearing balls seem to work slightly smoother than stainless in the printable setup as well.
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

bstiq, 2022-01-15:
Hopefully this covers everything.
There's also a version of the cheaper btu mod I modified to use screws rather than press fitting.

Thanks for the feedback LinuxBozo!

Regards,

artlugovoy, 2024-06-13:
> FWIW, I'm actively using the printable BTU mod on a 4x6 with great success. Works so much smoother than the roller bearings. Si3N4 ceramic bearing balls seem to work slightly smoother than stainless in the printable setup as well. 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

Tnis is awesome! Please could you share the adapter STL?

Closed 2022-01-15.

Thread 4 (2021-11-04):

Undersized insert hole in 3x5 Charybdis STL

bjvanst, 2021-11-04:
The screw hole behind the thumb cluster in the STL for the 3x5 Charybdis is undersized compared to the rest.  It's closer to 5mm instead of 6mm.

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

bstiq, 2021-11-04:
good catch. fixed ! thank you.

Closed 2021-11-04.

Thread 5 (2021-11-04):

3x5 Charybdis missing switch notches on thumb switches

bjvanst, 2021-11-04:
Printed the Charybdis 3x5 yesterday and noticed that the two thumb switches are missing the bottom notches for the clips on MX switches.  Confirmed they are missing from the STL and not just an artifact in my print.

bstiq, 2022-05-17:
Hey,

This is an issue yes.
It is fixed in the new v4 skeletyl, but still not on the cnano.

As every new version requires intensive testing, I'm not willing to introduce new files just for this, this is not an issue during build.

I will add those on the next major update.

Thanks for the feedback!

Regards,

Closed 2022-05-17.

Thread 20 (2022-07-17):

thumb keys missing notch to hold switch

dillonbheadley, 2022-07-17:
looks like the notches in the thumb cluster is missing a second notch to hold the switch in place. had a similar issue with the v2 skeletyls

Closed 2022-07-19.

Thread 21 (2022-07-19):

Charybdis 4x6 non-trackball side

waboni1, 2022-07-19:
Hi, awesome work, just planing to print the case before purchasing the kit, but noted that the STL for the non-trackball side is not present for the 4x6 Charybdis. Can you please upload the file. It would be greatly appreciated.

Cheers, Walt

waboni1, 2022-07-19:
Sorry, I didn't read "Made to be used with the Scylla or Skeletyl on the other half". this responded my own question.

Closed 2022-07-19.

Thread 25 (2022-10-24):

Modding for a left handed user?

WardLT, 2022-10-24:
Very novice question: what would it take to mod this design for a lefty? My spouse loves the design but has limited use of her right hand.

bstiq, 2022-10-24:
Hello,

You can mirror the case, plate and tent.

All the rest (adapter

Closed 2022-10-24.

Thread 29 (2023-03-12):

Broken loft creates a 'crack' in the Charybdis thumb cluster

octarinesun, 2023-03-12:
Just formally submitting the issue from a discord discussion

files/3x5 nano/charybdisnano_v2_v187.step

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
(Submitted by another user)

From cura:
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

bstiq, 2023-12-05:
fixed in latest version, closing

Closed 2023-12-05.

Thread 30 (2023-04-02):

Keyboard 4x6

brunooomelo, 2023-04-02:
do you have any 4x6 model keyboard without balltrack?

Boshimanu, 2023-04-03:
Hi, I'm searching for the same thing, but I do not find it... Are we missing something?
I don want to buy a kit, but I wanted to print it first to see how it works for me.... Awesome Project. Thanks!

bstiq, 2023-04-03:
Hello

Yes, check out the Scylla:
https://github.com/bastardkb/scylla

Regards,

hughrawlinson, 2023-06-13:
Hey, to follow up on this repo, the 4x6 model here seems to only contain the left hand model with the trackball as a step file, the right hand model with the trackball as an stl file, and supporting files like the trackball adapter and the tent. To be a bit clearer with your previous comment - on [the website](https://bastardkb.com/product/charybdis-kit/), which shows a picture of a Charybdis set with the trackball on the right and a non-trackball left hand - is that left hand using the Scylla model?

Thanks for all your work on this!

bstiq, 2023-06-14:
Hey,

If you want the right hand on the trackball, you should mirror the charybdis file.
You can do that using eg. prusaslicer.

For the left hand, you should use the scylla model yes.

All files are reversible, including plates and tents.
For tents, the charybdis ones are compatible with the Scylla.

hughrawlinson, 2023-06-14:
Thanks! 😊

shayded-exe, 2023-12-07:
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

Could you please explicitly mention this somewhere in the readme? I didn't realize until after printing that I printed the left handed trackball! The files also should be named left/right for clarity.

bstiq, 2023-12-11:
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

I'm not sure what you mean here, the Charybdis STL file is right handed already.

bstiq, 2023-12-12:
The STEP file is not meant for printing, but for editing.
I understand the STL file not oriented correctly might be an issue for printing as it sometimes is used for beginners, so when releasing a new charybdis version I take the time to mirror it properly.

If you're going to use the STEP file it probably means you're modifying the keyboard, so I'm assuming you know what you're doing.
I'm providing it out of convenience for advanced tinkerers.

shayded-exe, 2023-12-13:
> The STEP file is not meant for printing, but for editing. I understand the STL file not oriented correctly might be an issue for printing as it sometimes is used for beginners, so when releasing a new charybdis version I take the time to mirror it properly.
>
> If you're going to use the STEP file it probably means you're modifying the keyboard, so I'm assuming you know what you're doing. I'm providing it out of convenience for advanced tinkerers.

Do consider that most slicers support STEP now and in doing so can produce better optimized gcode (mainly for circles and arcs). I always print the STEP file when one is available.

Not a big deal either way :)

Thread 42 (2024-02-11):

Mirrored Charybdis stl and step files for 4x6

mjgadient, 2024-02-11:
charybdis3_v131.stl and charybdis3_v134.step in files/4x6 are both mirrored on the x-axis.

bstiq, 2024-02-12:
Fixed as of https://github.com/Bastardkb/Charybdis/commit/d84ca4e84d69b3168ed053a886b3f8b438981cf9

Closed 2024-02-12.

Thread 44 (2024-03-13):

Request for Kailh Hot-swappable PCB Socket  boards and USB C board to board connecters

starbuxed, 2024-03-13:
Kailh Hot-swappable PCB Socket.... as they are easier to solder.  The mil sockets dont work great with a hot plate  and the kaili sockets are easier to solder with shaky hands. I have nightmares still from iris v4 and the mil sockets.

Also  update the board to board connectors to USB C  as its much easier to find Usb C cables than trrs. especially with small patch cables.

It would bring the project in line with most current keyboards.

bstiq, 2024-03-13:
Hey,

We won't support hotswap - you can read more about it here:
https://docs.bastardkb.com/help/faq.html#hotswap
This is also why none of the other 3d keyboards won't support it (well, those manufactured in more than very small quantities).
If you want to fork the PCB project and modify the files, we would gladly accept a PR to link your repo as a mod.

For the board-to-board connection, we are sticking to audio cable because:
- it's a standard amongst the split keyboard world
- there are a lot of fancy audio cables, for aesthetic purposes
- having usb-c to usb-c brings *a lot* of problems (1)

(1) mostly design issues, to make sure plugging the wrong cable in the wrong port won't fry something. Plus all the confused users...

Hope it makes sense!

starbuxed, 2024-03-13:
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

Well  a majority of the spilt keeb is moving to usb-c or wireless....like  Beekeeb, keebIO,.... Now we are talking about people building keyboards.  You really think people are going to plug them in wrong.  And then its just a matter of wiring the power correctly.  Which is why you still see trrs jacks on splits trrs is simple. and people are unwilling to wade into the complexity that is usb c.  also there are a ton of established projects using the trrs... so they copy/ use that too. as far as the custom cables there are plenty of people who make the c to c ports as well... So as long as you wire them up correctly there is no risk.

sevenrats, 2025-01-12:
url is now https://docs.bastardkb.com/faq.html

sevenrats, 2025-01-12:
https://ryanis.cool/cosmos/plum-twist/

Closed 2024-03-13.

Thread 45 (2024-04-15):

Add more tenting options for 3x6

dudicoco, 2024-04-15:
Hi,

Currently the 3x5 has multiple tenting options (5, 15 and 30 degrees), while the 3x6 only has 30 degrees tents.

Would it be possible to add 5 and 15 degrees tent stl files for the 3x6 as well?

Thanks

bstiq, 2024-04-15:
Hey,

At the moment we don't have any design files for 5 and 15 degree tents.
If you'd like to create them you can use the plate files and we'd gladly accept a PR.

Regards,

Closed 2024-04-15.

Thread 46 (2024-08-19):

Charybdis 4x6 tent, indented version does not match version in file

jeroenvanwijgerden, 2024-08-19:
Minor detail, I would understand you if you were to ignore this.

[https://github.com/Bastardkb/Charybdis/blob/main/files/4x6/tent_alien_30deg_v127.stl](https://github.com/Bastardkb/Charybdis/blob/main/files/4x6/tent_alien_30deg_v127.stl)

File says v127, indentation says v1_124.

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

bstiq, 2024-08-19:
Hello,

Thanks for the notice.
The file name is based on the overall design (charybdis), so I must have done some changes on the Charybdis or plate as well before exporting the tent.
The number on the tent is for internal use, the file that's on github is always the latest version.

Closed 2024-08-19.

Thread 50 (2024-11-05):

MK2 right case missing ?

secteur0, 2024-11-05:
Hi,

I can not find the stl file for the right case of MKZ as spécified in the README (https://github.com/Bastardkb/Charybdis/blob/main/readme.md?plain=1#L38). I only see the left case (https://github.com/Bastardkb/Charybdis/blob/main/files/4x6/MK2/charybdis_v4_247.stl). Normal ?

Thank you for your hard work.

bstiq, 2024-11-06:
Hey,

To get the right case, you can simply mirror it. All the 3d models are reversible.

Closed 2024-11-06.

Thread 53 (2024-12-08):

printed parts vom: 4x6 top adapter

burkfers, 2024-12-08:
The list still says `4x6/adapter_top.stl` but the file is now located in `4x6/mk1`

bstiq, 2024-12-09:
I moved the file back to the correct location, thanks!

burkfers, 2024-12-09:
The file has not moved and the readme is (in that section) unchanged. Forgot to push?

bstiq, 2024-12-09:
Something something mondays

Closed 2024-12-09.

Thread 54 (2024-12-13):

broke documentation when you silently migrated to 3mf

sevenrats, 2024-12-13:
commit 2dad0ca removes the file linked in the docs and replaces the stl with a 3mf file. need to change file name in readme

bstiq, 2024-12-13:
Hey,

- Can you link where the docs broke? I don't expect a 3mf vs stl difference is an issue, it's difficult to track changes like that
- Can you expand on the lack of compatibility of 3mf on linux? As long as you have a slicer (eg. Prusaslicer, Orcaslicer..) it should be fine

sevenrats, 2024-12-13:
the linux problems were just my ignorance,  I was down one of these rabbit holes:
https://github.com/SoftFever/OrcaSlicer/issues/6800
https://github.com/3MFConsortium/gladius/issues/3

but I understand now how the migration was the correct decision.

https://github.com/Bastardkb/Charybdis/pull/55

bstiq, 2024-12-14:
We can eventually add a note about the STL/3MF file interchangeability

bstiq, 2024-12-29:
Fixed with https://github.com/Bastardkb/Charybdis/commit/0fbf4346a73e6e77c5d61bf478446d3cc5d47789

Closed 2024-12-29.

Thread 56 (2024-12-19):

Change trackball polling rate?

Rouji, 2024-12-19:
Hi!
I recently got a 120hz display and noticed the trackball in my Charybdis seems to only update at 60-ish Hz. Not sure how I can actually measure that, but it's definitely less than my other mice.
I tried changing `USB_POLLING_INTERVAL_MS`, but that didn't do anything.
Anything I can do to make it poll faster?

Rouji, 2024-12-30:
Aha!
Figured out it's not a setting, but something to do with RGB. If I turn RGB off, my pointer is nice and smooth. Turn it on, and it goes down to the horrible inconsistent 50~60Hz.

Guessing the controller can't keep up with both things at once? :thinking:

Rouji, 2024-12-30:
The lagginess happens when:
- RGB is on
- AND the auto mouse layer is active
-  AND CHARYBDIS_CONFIG_SYNC is on

...which in my case was always the case whenever I used the trackball. I have no idea why this combination of things makes it lag, but disabling CHARYBDIS_CONFIG_SYNC seems to completely fix this

Rouji, 2024-12-30:
actually, it might be on any layer that's not the base layer. not specifically the auto mouse layer

bstiq, 2025-01-06:
Hello,

I don't have a high refresh rate display on hand, so I will ask around in the discord community.

bstiq, 2025-01-06:
To help further, can you detail:
- your hardware (RP2040 splinktegrated? blackpill? etc)
- if you are using the latest firmware code from the BKB QMK fork (on bkb-master branch)
- if you tried using a different computer / screen already

Even on old firmware the default polling rate should be at least 125Hz, so we are investigating.
It could be an issue with half duplex communication.

Could you maybe link us your uf2 image here so we can test on our end?

bstiq, 2025-01-06:
According to KarlK90:

> Is the USB connection on the same side as the Trackball? Otherwise all the mouse reports are synced over the serial connection which might lead to congestion. If that solves the issue the problem is probably the limited bandwidth. Bumping the serial speed would help with that.

daskygit, 2025-01-06:
Does the issue also appear if you lower the brightness? Turn it pretty much all the way down.

Rouji, 2025-01-06:
Ah yeah, kinda forgot there's different versions of things.
This is:
- splinky v3
- just basic upstream qmk
- usb on same side as trackball

and it happens on different PCs, and on all brightnesses (except off)

bstiq, 2025-01-07:
Some tests by Dasky:
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

> while not brilliantly consistent, it's certainly smooth to my eye on a 240hz monitor

Did you also try using different cables? Maybe a different screen if you can as well.

Rouji, 2025-01-07:
Yeah I tried different cables, computers, screens, and OSs.

I'm not really dependent on CHARYBDIS_CONFIG_SYNC, and disabling that completely fixes this problem, so I'm pretty much happy again.

But I'll try the default firmware and stuff just as a matter of interest

Rouji, 2025-01-07:
Can't reproduce with the vendor image, but I'm not sure the circumstances even apply with that(?)

bstiq, 2025-01-09:
So this seems like it's an issue with the config sync.
As it's an isolated bug, I'll close this for now, feel free to reopen if there's further issues or someone else with the same issue.

Closed 2025-01-09.

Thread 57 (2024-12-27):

Readme says right STL, but left is provided

durza777, 2024-12-27:
Readme in the base of repo says to print "4x6/MK2/charybdis.stl" for the right half, but an STL of the left was provided. You may think nobody would print without looking closely, but I did. Looks like the plate is for the left as well, which also does not match the readme.

bstiq, 2024-12-30:
thanks, updated

Closed 2024-12-30.

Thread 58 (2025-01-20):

bug: outside ring starts at layer 2 for `mods/static-bearing-screws/balls-3.1mm  /tall-inserts.stl`

ZerGo0, 2025-01-20:
I'm pretty sure that this is not intended.
Layer 1:
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
Layer 2:
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

Didn't mess up my print, but still pretty scary 😅

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

bstiq, 2025-01-27:
This mod was made by @alairock , can you weigh in on that?
Should be a fast fix, but I don't have the source files on hand

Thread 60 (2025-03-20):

No case arrived :(

akuryan, 2025-03-20:
https://github.com/Bastardkb/Charybdis?tab=readme-ov-file#get-a-kit-from-bastardkb states that in order would be included case.

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

On the order page there is no separate option to skip ordering case or to include it - so, my expectation was that I would receive a printed case as well. BUT, in arrived order I only have PCB and electronics
I do not have access to 3d printer to be able to print it myself. I would love to be able to select that I want a case and tents to be included.

bstiq, 2025-03-20:
Hello,

There is already an option on the website:

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

If you need me to send you the 3d prints that's possible, please send an email to support@bastardkb.com with your order number!

Regards,
Q. Lebastard
Bastard Keyboards

Closed 2025-03-20.

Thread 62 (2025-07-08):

README mentions Chary is meant to be used with one of the other models, but Chary DIY kit mentions nothing of the sort.

Desolar1um, 2025-07-08:
Hello,

Thanks for all the hard work.
I'm looking to buy a Charybdis DIY kit in the near future, and to 3D print the case myself. I am confused by whether the DIY kit comes with only 1 side (lets say right side parts + trackerball), and I need another DIY kit for one of the other models, or it comes with all I need for both sides.

If it is the latter (i.e kit for 2 Charys, with trackerball on one side), the of not is that the Chary files are missing a Case STL without trackerball.

Closed 2025-07-09.

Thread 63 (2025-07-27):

3x6 Mini. Plate and tent don't fit the case

suxscribe, 2025-07-27:
[plate_flush_v1_v1.stl](https://github.com/Bastardkb/Charybdis/blob/main/files/3x6%20mini/plate_flush_v1_v1.stl) and [tent_3x6_5deg_flush.stl](https://github.com/Bastardkb/Charybdis/blob/main/files/3x6%20mini/tent_3x6_5deg_flush.stl) are a bit smaller than the case.
It seems the countour is offset by about 1.5mm

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

Closed 2025-07-29.

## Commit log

2021-08-02 add files and pic
    [adapter_v125_bottom.stl, adapter_v125_holder.stl, adapter_v125_top.stl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]
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2021-08-05 fix nano file
    [charybdisnano_v2_v148.stl]
2021-08-05 add marker for easier installation
    [adapter_v2_top.stl, adapter_v3_top.stl]
2021-08-06 new plate and adapter
    [adapter_v2_bottom.stl, adapter_v2_bottom_v41.stl, adapter_v2_holder.stl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]
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2021-08-06 export correct versions
    [adapter_v2_bottom_v41.stl, adapter_v2_top_v41.stl]
2021-08-09 M4 holes to M3 (correct size)
    [adapter_v2_bottom_v41.stl, adapter_v2_bottom_v48.stl]
2021-08-09 stronger anti slip pad
    [tent30deg_v2.stl, tent30deg_v4.stl]
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2021-08-09 add space for lens
    [sensor_cover_v48.stl, sensor_cover_v51.stl]
2021-08-09 move holder away from lens
    [adapter_v2_bottom_v50.stl, adapter_v2_bottom_v51.stl]
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2021-09-06 better fitting for shield and ports
    [charybdisnano_v2_v148.stl, charybdisnano_v2_v154.stl]
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2021-09-20 update plate and port size
    [adapter_btu_bottom_v28.stl, charybdis3_plate_v129.stl, charybdis3_plate_v133.stl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]
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2021-10-12 make btu adapter universal
    [adapter_btu_bottom_v28.stl, adapter_btu_bottom_v32.stl]
2021-10-21 tent and adapter stuff
    [adapter_v2_bottom_v58.stl, adapter_v2_bottom_v61.stl, adapter_v3_v17_bottom.stl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]
2021-10-27 add missing screw chamfer
    [adapter_v2_bottom_v61.stl, adapter_v2_bottom_v62.stl]
2021-11-04 fix screw insert hole too small
    [charybdisnano_v2_v154.stl, charybdisnano_v2_v158.stl]
2021-11-05 fix model
    [charybdisnano_v2_v158.stl]
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2022-01-22 smaller and stronger holes for nylon
    [tent30deg_organic_plate_attachment_v45.stl]
2022-02-11 switch to only one kind of organic tent
    [tent30deg_organic_plate_attachment_v34.stl, tent30deg_organic_plate_attachment_v45.stl, tent30deg_plate_attachment_v35.stl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]
2022-03-22 more invert
    [charybdis3_plate_v133.stl, tent30deg_v13.stl]
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2022-04-11 add 3x5 trackpad mod
    [tent-connector.stl, trackpad-holder.stl]
2022-04-20 Add chair mount plate
    added stl and picture
    Added location
    Added spacing
    [charybdisNano_plate_v13.stl, charybdisnano_ChairMountPlate_v13.step]
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2022-05-02 add trackpad mod for trackball horder
    [bot.stl, top.stl]
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2022-05-02 file name limit for JLC
    [cnano_v2_nylon_v2_L.stl, cnano_v2_nylon_v2_R.stl]
2022-05-03 added 30 degree tents for 3x6
    [Organic Tent 30deg Charybdis 3x6.stl]
2022-05-12 reorganize folders, add alien tents
    [alien_v2_168.stl, plate_v150.stl, plate_voronoi_v1_v5.stl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]
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2022-05-17 new stronger top adapter
    [adapter_v3_v14_top.stl, adapter_v3_v22_top.stl]
2022-05-18 update to universal adapter
    [adapter_v2_bottom_v62.stl, adapter_v3_bottom_v22.stl]
2022-05-18 Revert "update to universal adapter"
    This reverts commit bf58c35924cfdfa11b00c486d98e4ea1453e143a.
    [adapter_v2_bottom_v62.stl, adapter_v3_bottom_v22.stl]
2022-05-27 easier to install screw inserts for tents
    [tent30deg_v13.stl, tent30deg_v17.stl]
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2022-06-03 add 15 degree tent
    [tent15deg_v2_25.stl]
2022-06-07 move pattern to fit reset button on splinky-bkb
    [alien_v2_168.dxf, alien_v2_168.stl, alien_v2_185.dxf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]
2022-06-08 add back hex plate
    [alien_v2_185.stl, hex_v1_150.stl]
2022-06-09 make screw inserts 5.5mm for nylon builds
    [charybdisnano_v2_v158.stl, charybdisnano_v2_v187.stl, cnano_v2_nylon_v2_L.stl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]
2022-06-09 smaller screw inserts for nylon 15deg
    [tent15deg_v2_25.stl, tent15deg_v2_27.stl]
2022-06-09 30 deg tent - smaller screw inserts
    [tent_v7_67.stl, tent_v7_68.stl]
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2022-06-27 Added STL files for modular thumb cluster
    [NewPlate.stl, Reg-Thumb.stl, Track-Thumb.stl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]
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2022-08-13 Added MountedMods changed to 3x5+3
    [3x5+3 V4T02 v11.stl, 3x5_3 high v2.stl, 3x5_3 low blackpill and standard v16.stl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]
2022-08-13 Moved fusion files to seperate folder
    [Top57mmTrackball v18.f3d, Top57mmTrackball30DegTentStand v4.f3d, TopEncoderMod v6.f3d]
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2022-09-18 fix broken cmini file
    [CMini.stl]
2022-11-07 Adding files and readme for mods
    [bottom-with-pad-connector.3mf, bottom.3mf, pads-arm.3mf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]
2022-11-09 Adding bottom case plates with hinges.
    [left-case-bottom-scylla.3mf, right-case-bottom-charybdis.3mf]
2023-03-04 Added angled wrist pads bases
    [pads-arm-short-for-angled-base.3mf]
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2023-04-05 added cover to cover the whole sensor
    [Sensor_cover.stl]
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2023-06-11 Added inside mount ring and clarity to high and low trackball
    [CharybdisRingMountMod v4.3mf]
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2023-08-16 hole in tent for splinktegrated
    [tent_alien_30deg_v125.stl, tent_alien_30deg_v127.stl]
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2023-08-21 feat: add arm extension
    [pads-arm-extended.stl]
2023-08-21 feat: shorter pad base
    [pads-base-short.stl]
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2023-08-22 chore: 3x5+3 file assets and descriptions
    [adapter_v2_bottom_adns-9800.stl, adapter_v2_bottom_adns_9800.stl, adapter_v2_bottom_pmw3389.stl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]
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2023-11-30 Added palmrest files
    stl, dwg, sldprt
    [Charybdis-PlamRest-Slope.DWG, Charybdis-PlamRest-Slope.SLDPRT, Charybdis-PlamRest-Slope.STL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]
2023-12-03 Add cnano 3d printed magsafe plate
    [magsafe_3dp_v0_1.stl]
2023-12-04 update mods readme, move files
    [Charybdis-PlamRest-Slope.DWG, Charybdis-PlamRest-Slope.SLDPRT, Charybdis-PlamRest-Slope.STL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]
2023-12-30 add ball-cover and screws-bottom
    [Ball_cover_resin_5mm.stl, bottom_resin_5mm.stl]
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2024-02-16 Printable BTU requires btu_bottom_v32
    I used printable BTU mod with 2.5mm ceramic balls and the README suggested to print the bottom.stl file from the printable-btu-screws, but it doesn't work because the ball is too high and too far from the sensor. Using the btu_bottom_v32.stl file solved the issue
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2024-04-16 rename printable BTU to static bearing
    [bottom.stl, bottom_resin_5mm.stl, inserts.stl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]
2024-06-24 fix veichu sensor distance
    credit: noongom
    [veichu.stl]
2024-06-24 add Cmini DXF cut plate
    [plate_v1_v11.dxf]
2024-07-30 update 4x6 dxf plate with splinktegrated hole
    [plate_shield2.x.dxf]
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2025-08-11 add files and readme for cmini,cnano snapfit pcb case
    [CMini_v1_v11_snap_fit.stl, case_v4_v99_snap_fit.stl, charybdisnano_v2_v187_snap_fit.stl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]
2025-08-11 add files and readme for cmini,cnano AA 3.7v battery holder
    [CMini_v1_v11_snap_fit_with_battery.stl, battery_holder_cover.stl, case_v4_v99_snap_fit_with_battery.stl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]
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
